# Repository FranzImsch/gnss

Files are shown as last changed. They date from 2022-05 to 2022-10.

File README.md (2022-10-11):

# [GNSS Rev. B](https://github.com/FranzImsch/gnss)

# Overview

[ZED-F9P](https://www.u-blox.com/sites/default/files/ZED-F9P-04B_DataSheet_UBX-21044850.pdf)\-based GNSS dev board with [ISM330DHCX](https://www.st.com/resource/en/datasheet/ism330dhcx.pdf) 6-DoF IMU, [BMM150](https://www.bosch-sensortec.com/media/boschsensortec/downloads/datasheets/bst-bmm150-ds001.pdf) Magnetometer and [DPS310](https://www.infineon.com/dgdl/Infineon-DPS310-DS-v01_00-EN.pdf?fileId=5546d462576f34750157750826c42242) pressure sensor.

As a basic UI, the OLED (1.5") can be used along with a navigation switch, more advanced usage requires a web interface. The device features a microSD card reader for data logging.

The ESP32 is used as the microcontroller because of its WiFi and Bluetooth capability that enables data to be streamed onto a device (phone, tablet, …) wirelessly.

The component selection is partly influenced by the semiconductor shortage. The software is yet to be worked on and also the documentation should receive some attention.

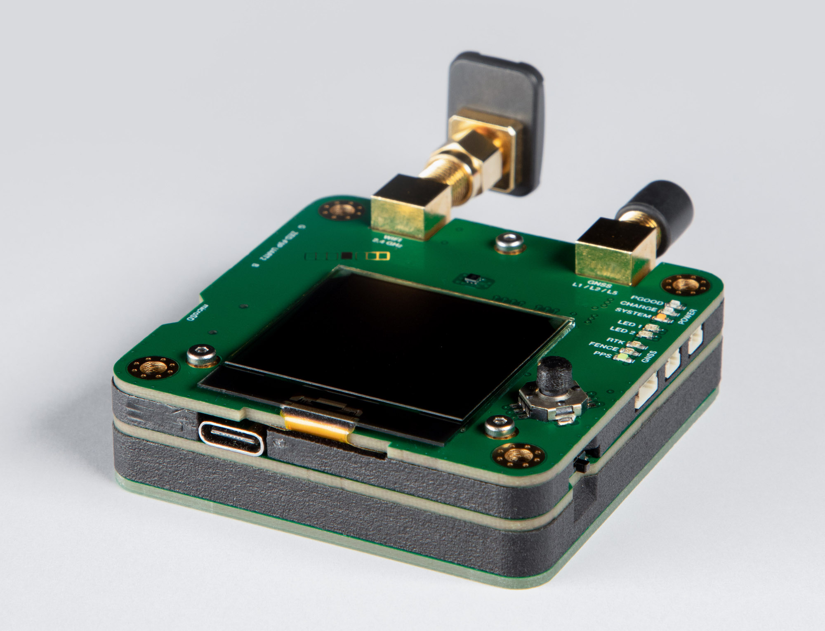
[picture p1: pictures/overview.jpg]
Overview (https://a360.co/38VXSXv)


# Hardware

The device consists of a stackup of three PCBs. A detailed view is provided by the [3D-model](https://a360.co/38VXSXv). The third PCB is not relevant for the function, as it only serves as a mounting piece for the battery.

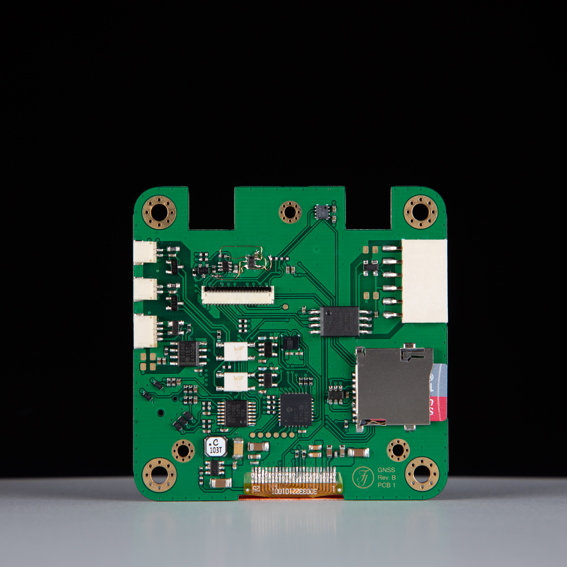
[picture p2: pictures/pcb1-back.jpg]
Photo of the backside of the PCB with the OLED
 The uppermost PCB of the stackup is where the OLED is mounted along with the navigation switch and some status LEDs. The photo shows the backside of this PCB with the IO ports and their isolation. Also found here is the barometric pressure sensor (top), a port expander and the 12V step-up converter for the OLED. One may ignore the little bodge at the top. :)

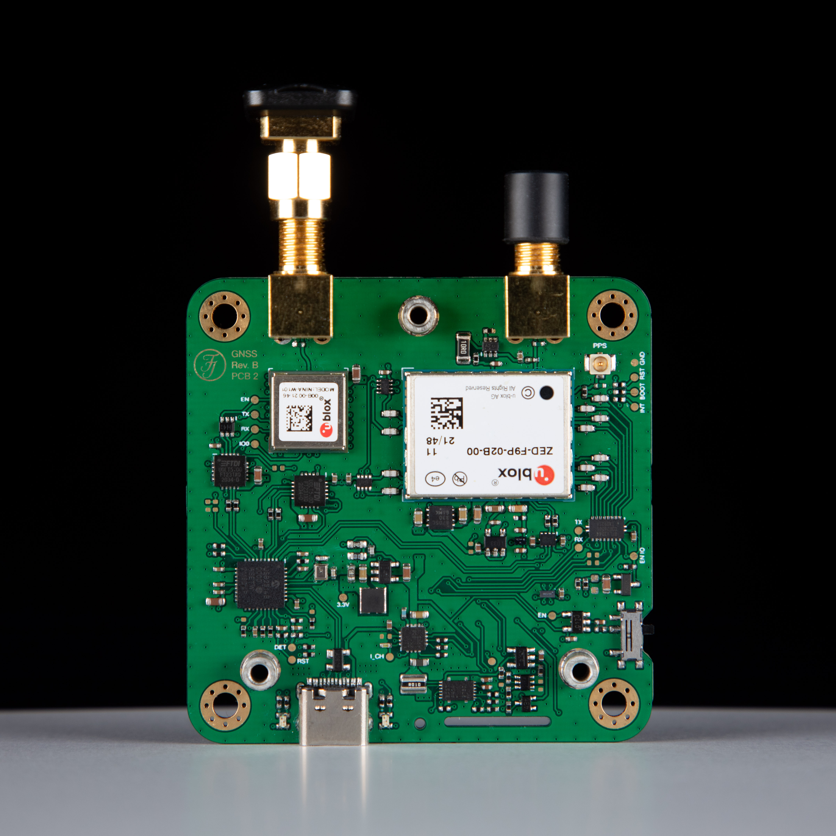
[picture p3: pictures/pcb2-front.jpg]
Photo of PCB with ZED module
 The picture shows the main PCB where the ZED module is located (right-hand side). On the left the ESP32 module can be found along with the FTDI chips for both the ESP and the UART1 port of the ZED-F9P. The bottom left is where the USB hub chip is placed. On the bottom-right there is the power section, consisting of a step-down converter, a power path manager, a fuel gauge for the battery and some super low-noise LDOs for the ZED-F9P.

## Battery

The function of the battery circuitry was tested extensively and no issues were found. The device correctly stops power when the cutoff voltage is reaced (3.2 V, depends on the voltage supervisor). During charging, the unit does not exceed ca. 60°C at the hottest point (which is the power path IC).

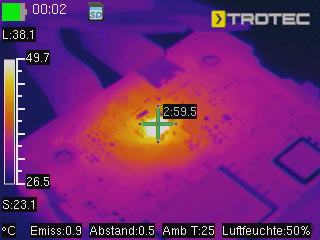
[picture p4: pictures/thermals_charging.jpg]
Thermal image of power path IC


## Documentation and Resources

[Schematic](https://franz.science/gnss/Schematic.pdf)  
[iBom PCB #1](https://franz.science/gnss/PCB-1/bom/index.html)  
[iBom PCB #2](https://franz.science/gnss/PCB-2/bom/index.html)

[3D model](https://a360.co/38VXSXv)

## Changelog (Rev A to B)

* Added LiPo battery to enable standalone operation
* Replaced BNO055 with ISM330DHCX and BMM150 due to their superior performance
* Removed SHT40 as the first revision revealed that the board heats up too much for temperature or humidity measurement (Can be added via exposed i2c connector)
* Added USB hub to board
* Protected ZED a bit more against electrical damage (isolating and filtering IO, LDO as power supply)
* many minor improvements

# GNSS in General

Useful literature:

* https://doi.org/10.1007/978-3-211-73017-1
* https://content.u-blox.com/sites/default/files/products/documents/GPS-Compendium_Book\_(GPS-X-02007).pdf?hash=undefined

---

# Licence

Copyright Franz Imschweiler 2022.

This source describes Open Hardware and is licensed under the CERN-OHL-S v2 or any later version. You may redistribute and modify this source and make products using it under the terms of the CERN-OHL-S v2 or any later version (https://ohwr.org/cern_ohl_s_v2.txt).

This source is distributed WITHOUT ANY EXPRESS OR IMPLIED WARRANTY, INCLUDING OF MERCHANTABILITY, SATISFACTORY QUALITY AND FITNESS FOR A PARTICULAR PURPOSE. Please see the CERN-OHL-S v2 for applicable conditions.

Source location: https://github.com/FranzImsch/gnss

As per CERN-OHL-S v2 section 4, should You produce hardware based on this source, You must where practicable maintain the Source Location visible on the external case of the GNSS Receiver or other products you make using this source.

---

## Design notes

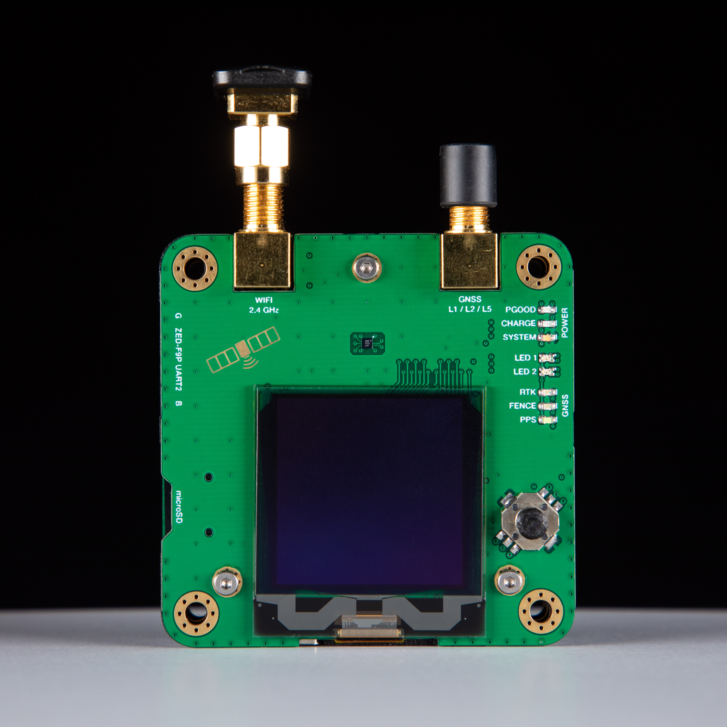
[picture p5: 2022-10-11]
pictures/pcb1-front.jpg

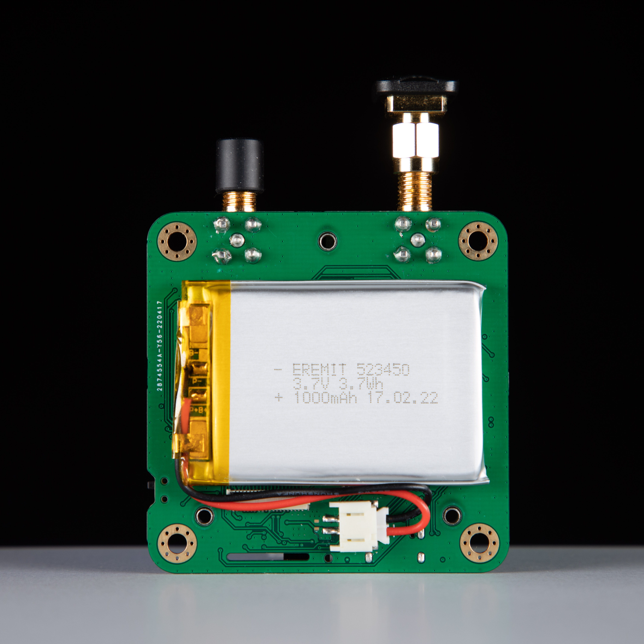
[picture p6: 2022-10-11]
pictures/pcb2-back.jpg

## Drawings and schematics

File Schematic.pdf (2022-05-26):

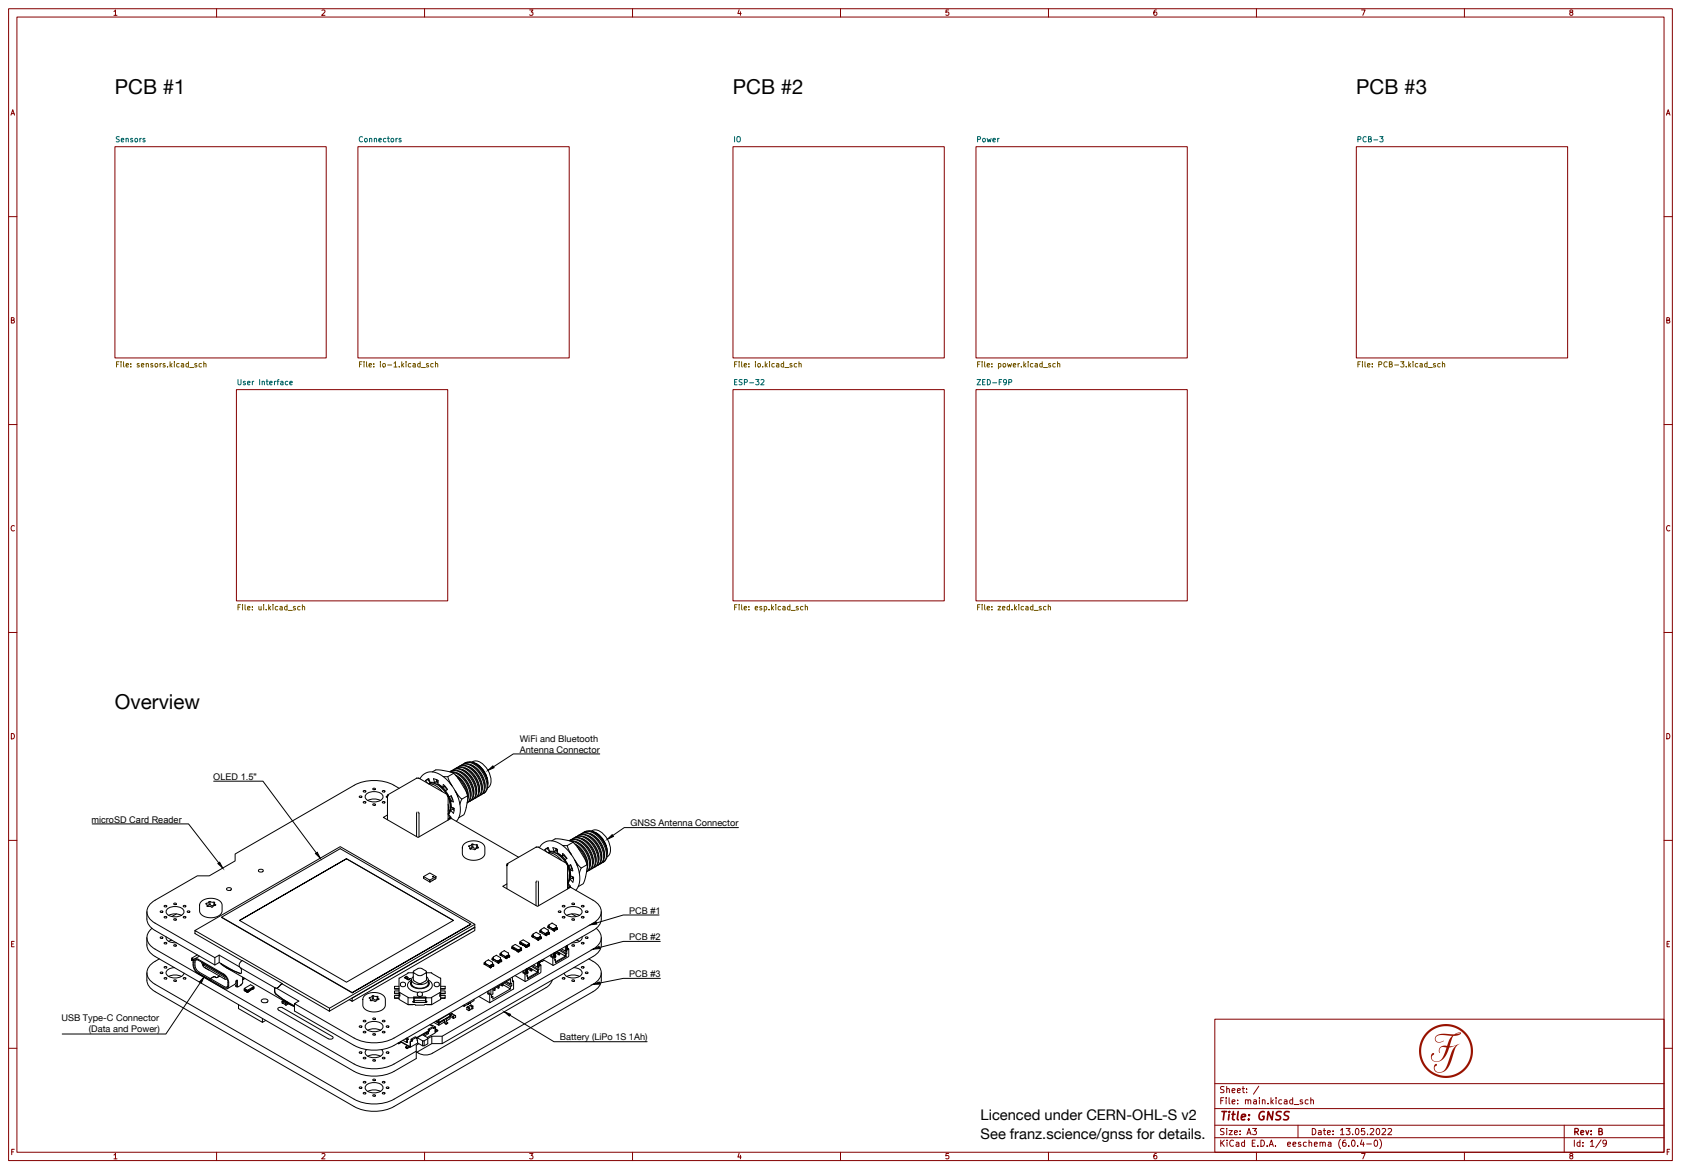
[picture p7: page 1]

Licenced under CERN-OHL-S v2
See franz.science/gnss for details.

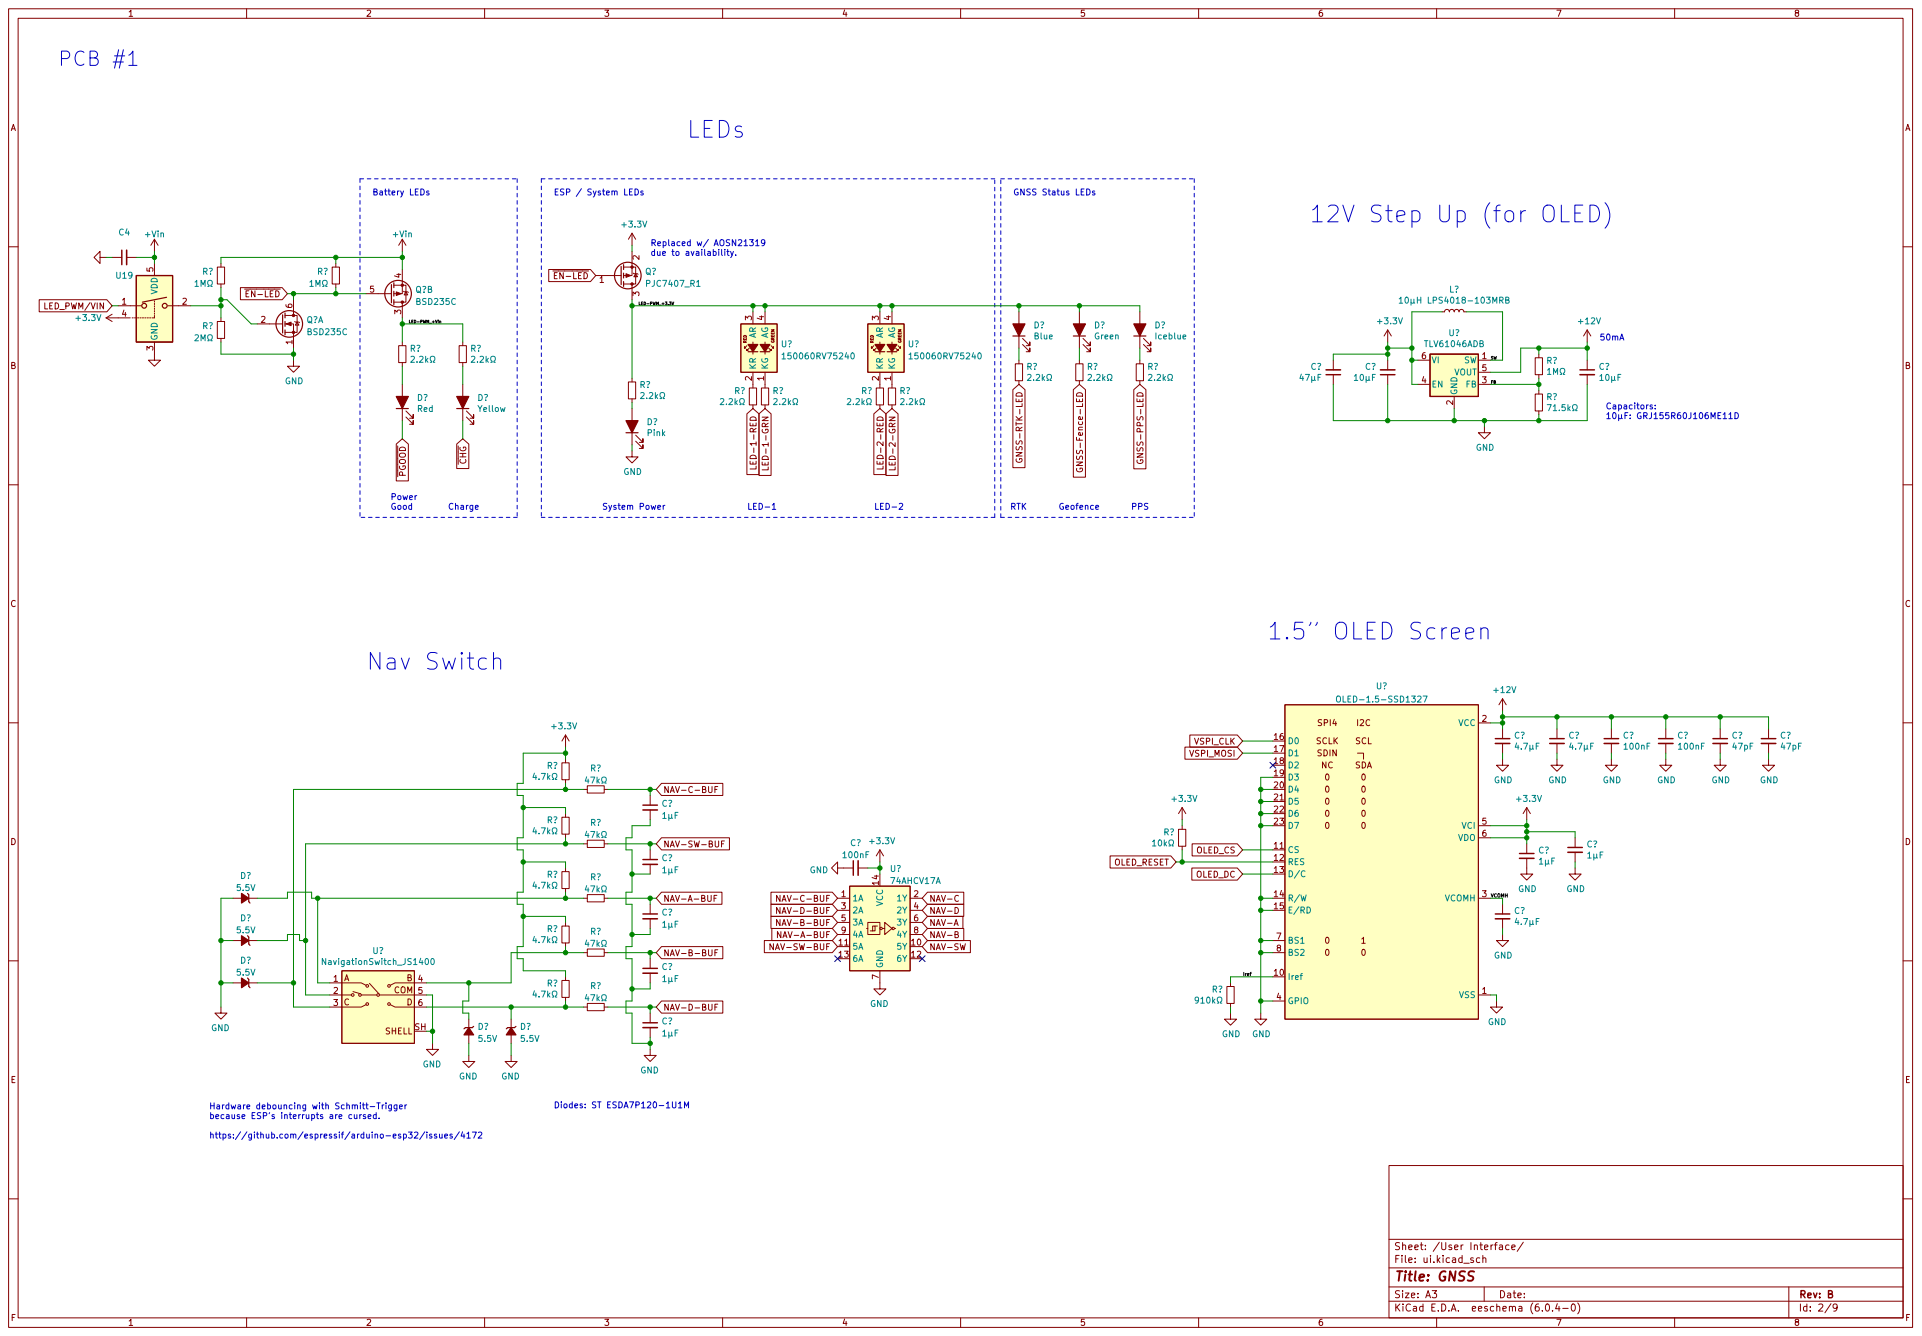
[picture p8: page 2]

12V Step Up (for OLED)

Hardware debouncing with Schmitt-Trigger
because ESP's interrupts are cursed.

https://github.com/espressif/arduino-esp32/issues/4172

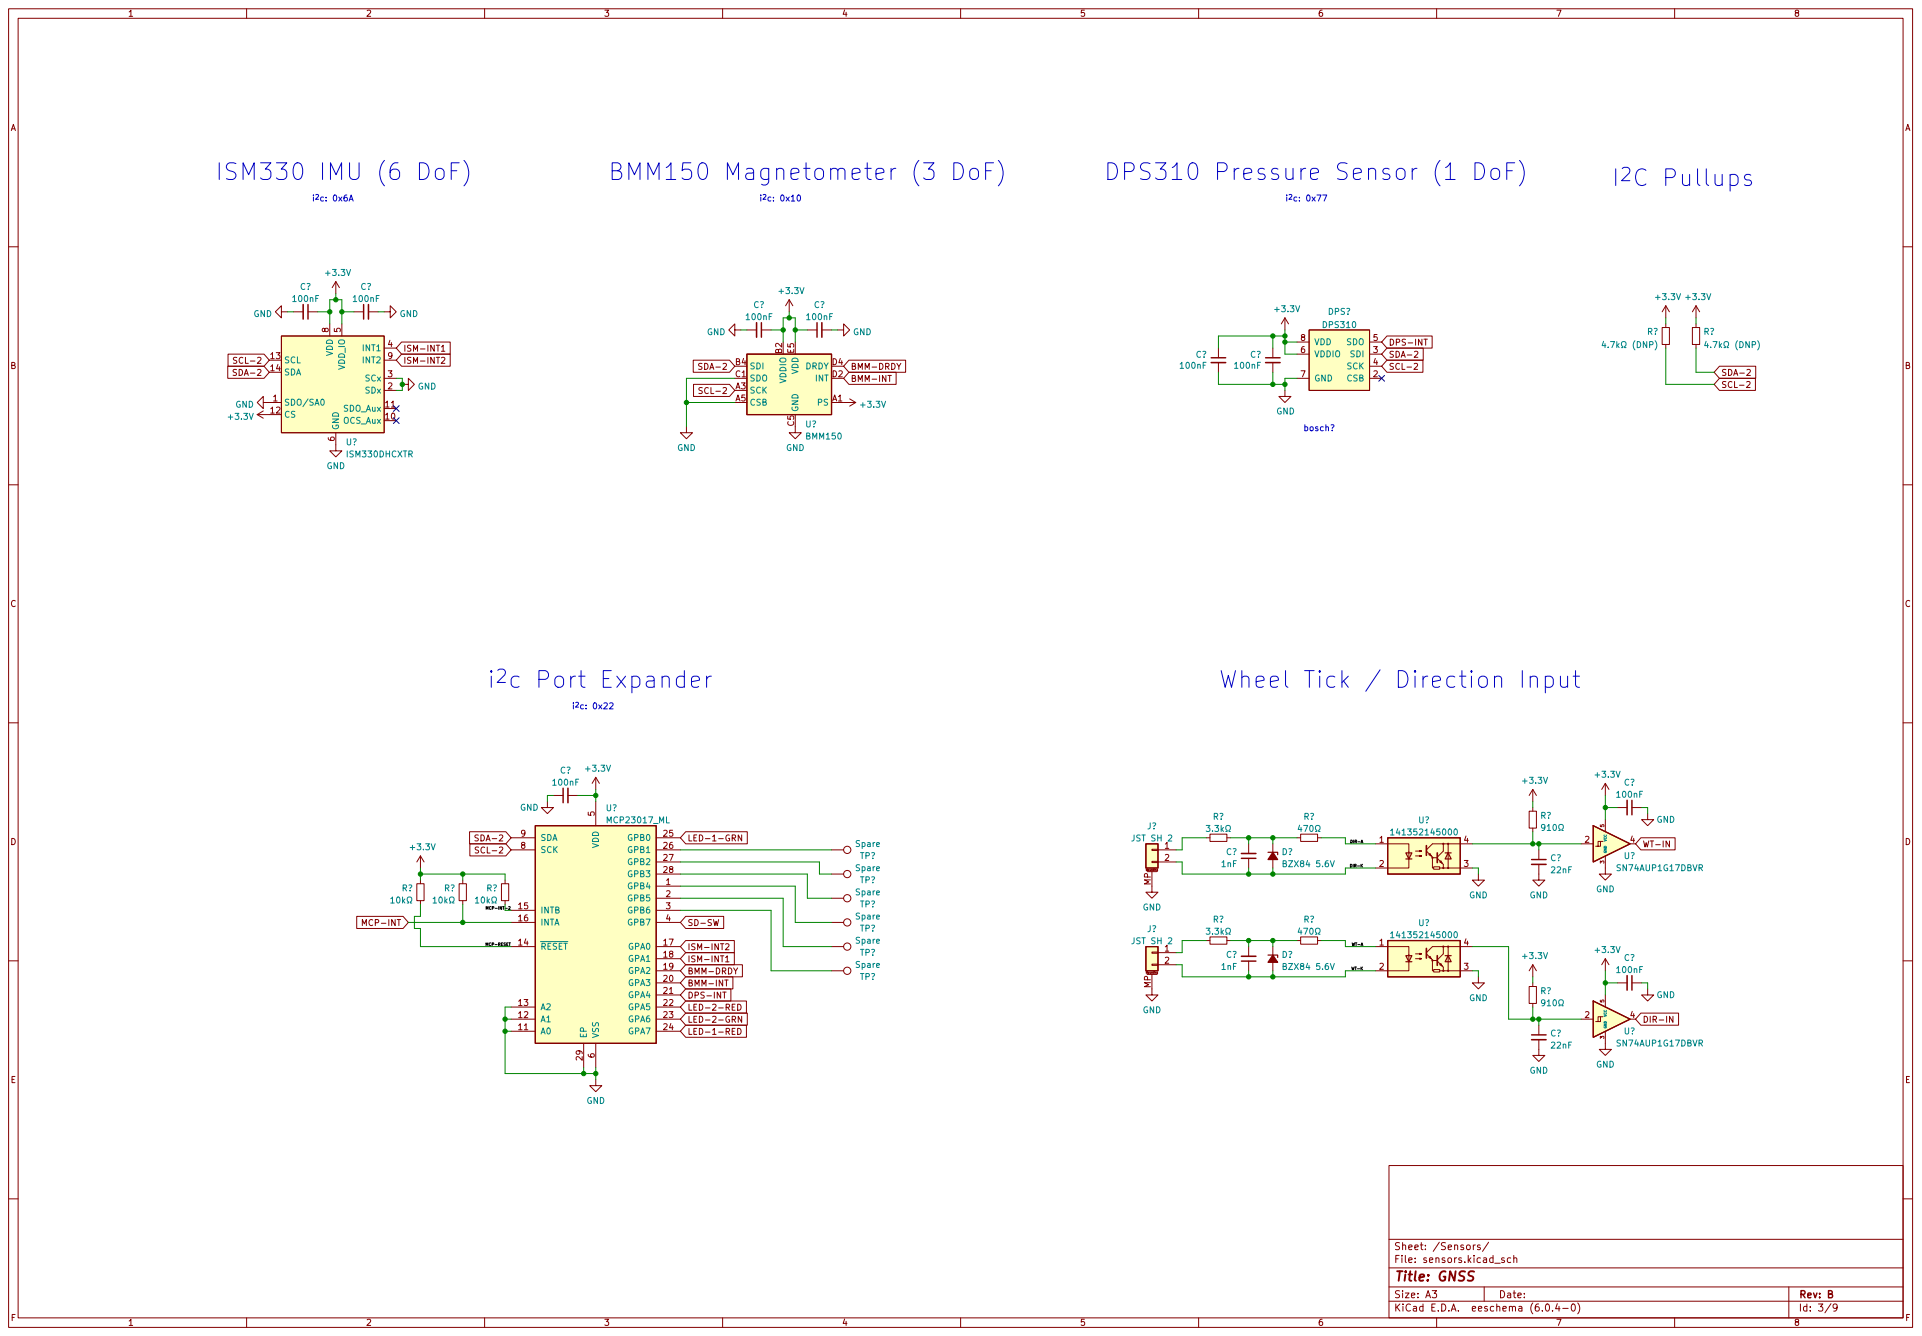
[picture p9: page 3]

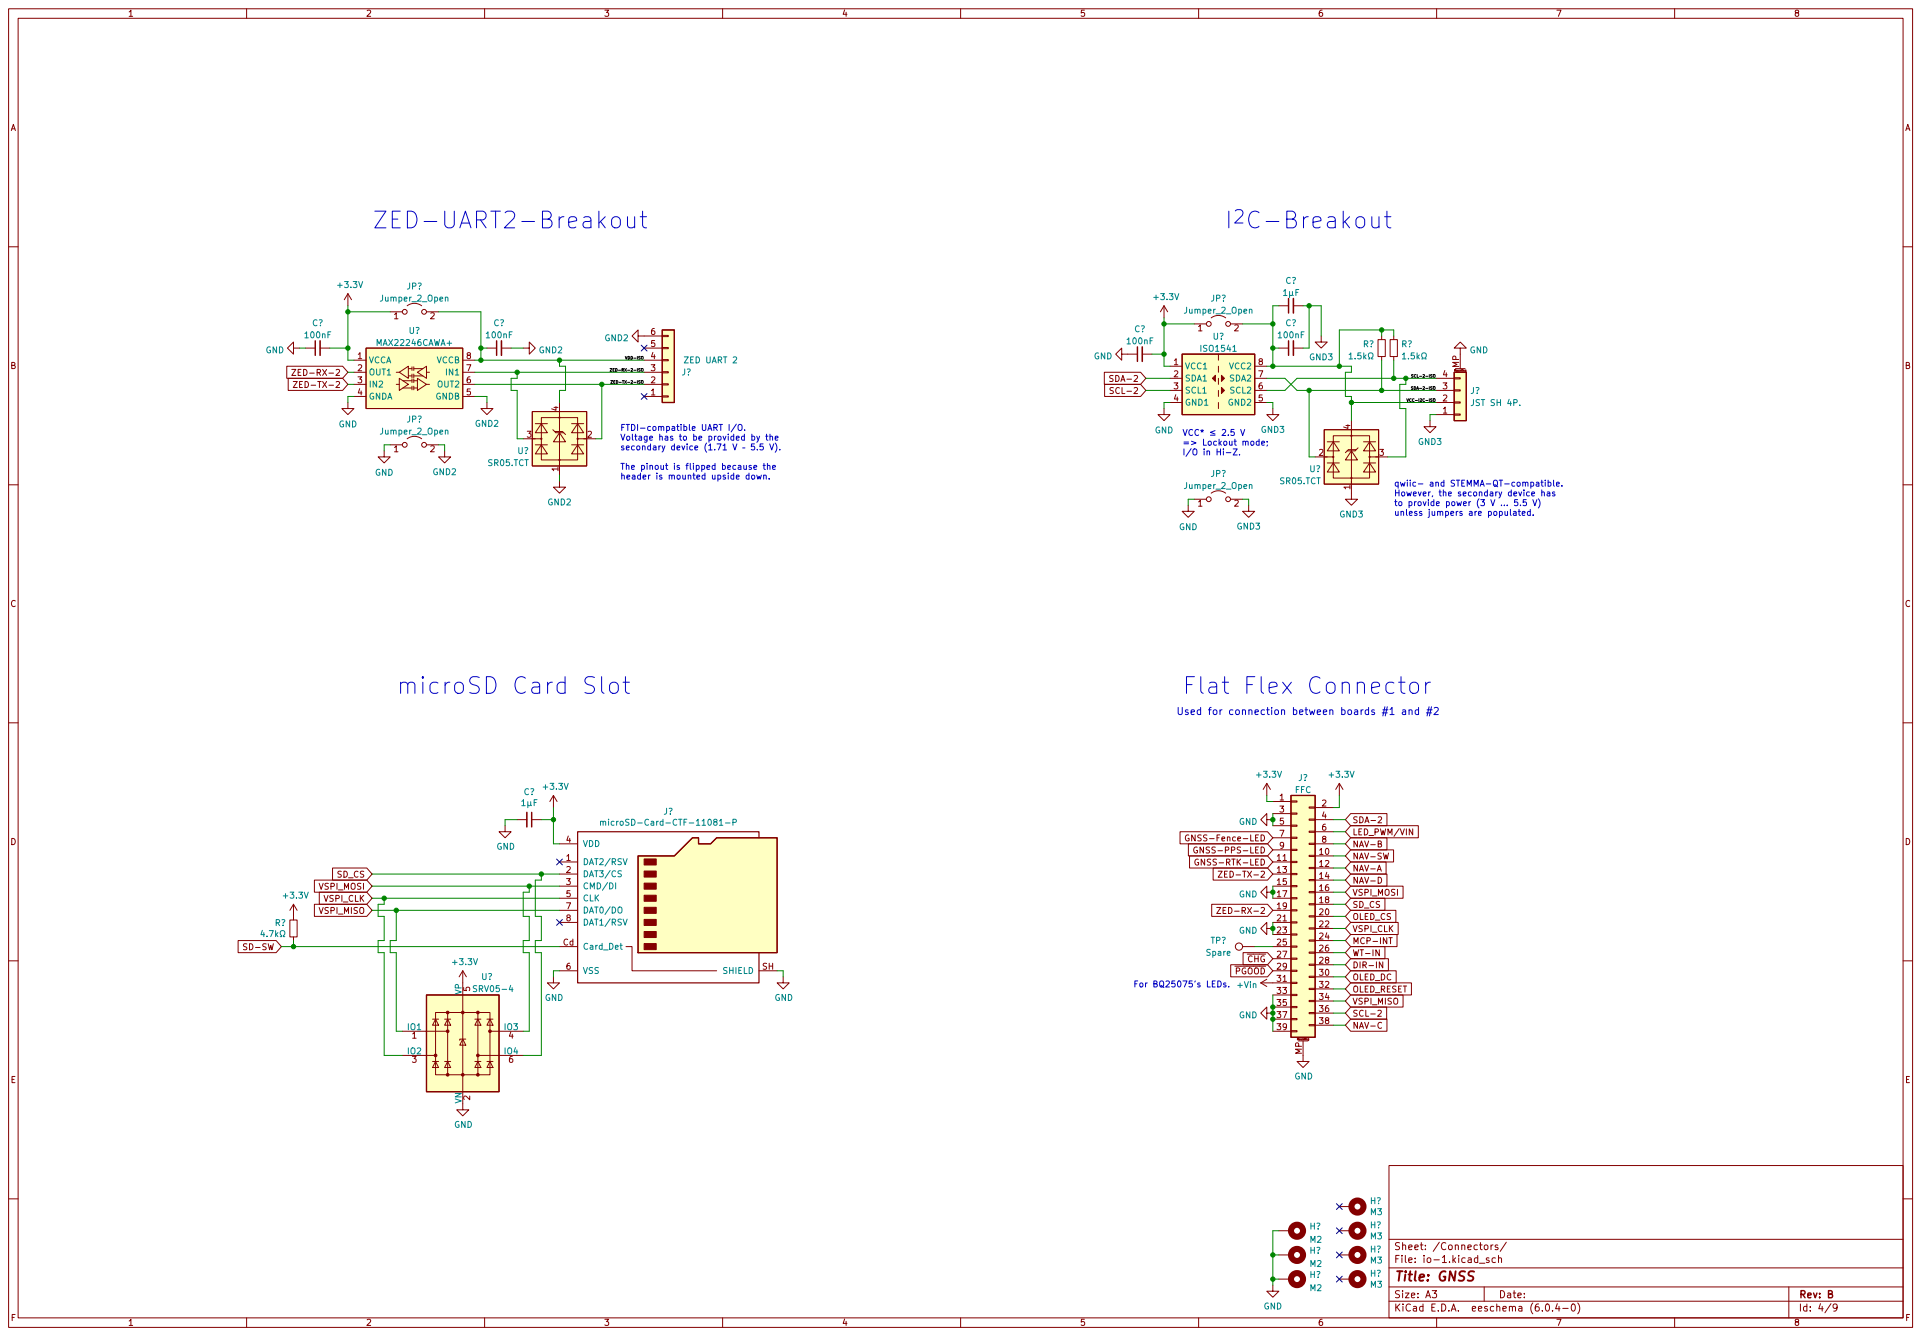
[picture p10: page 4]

FTDI-compatible UART I/O.
Voltage has to be provided by the

The pinout is flipped because the
header is mounted upside down.

qwiic- and STEMMA-QT-compatible.
However, the secondary device has
unless jumpers are populated.

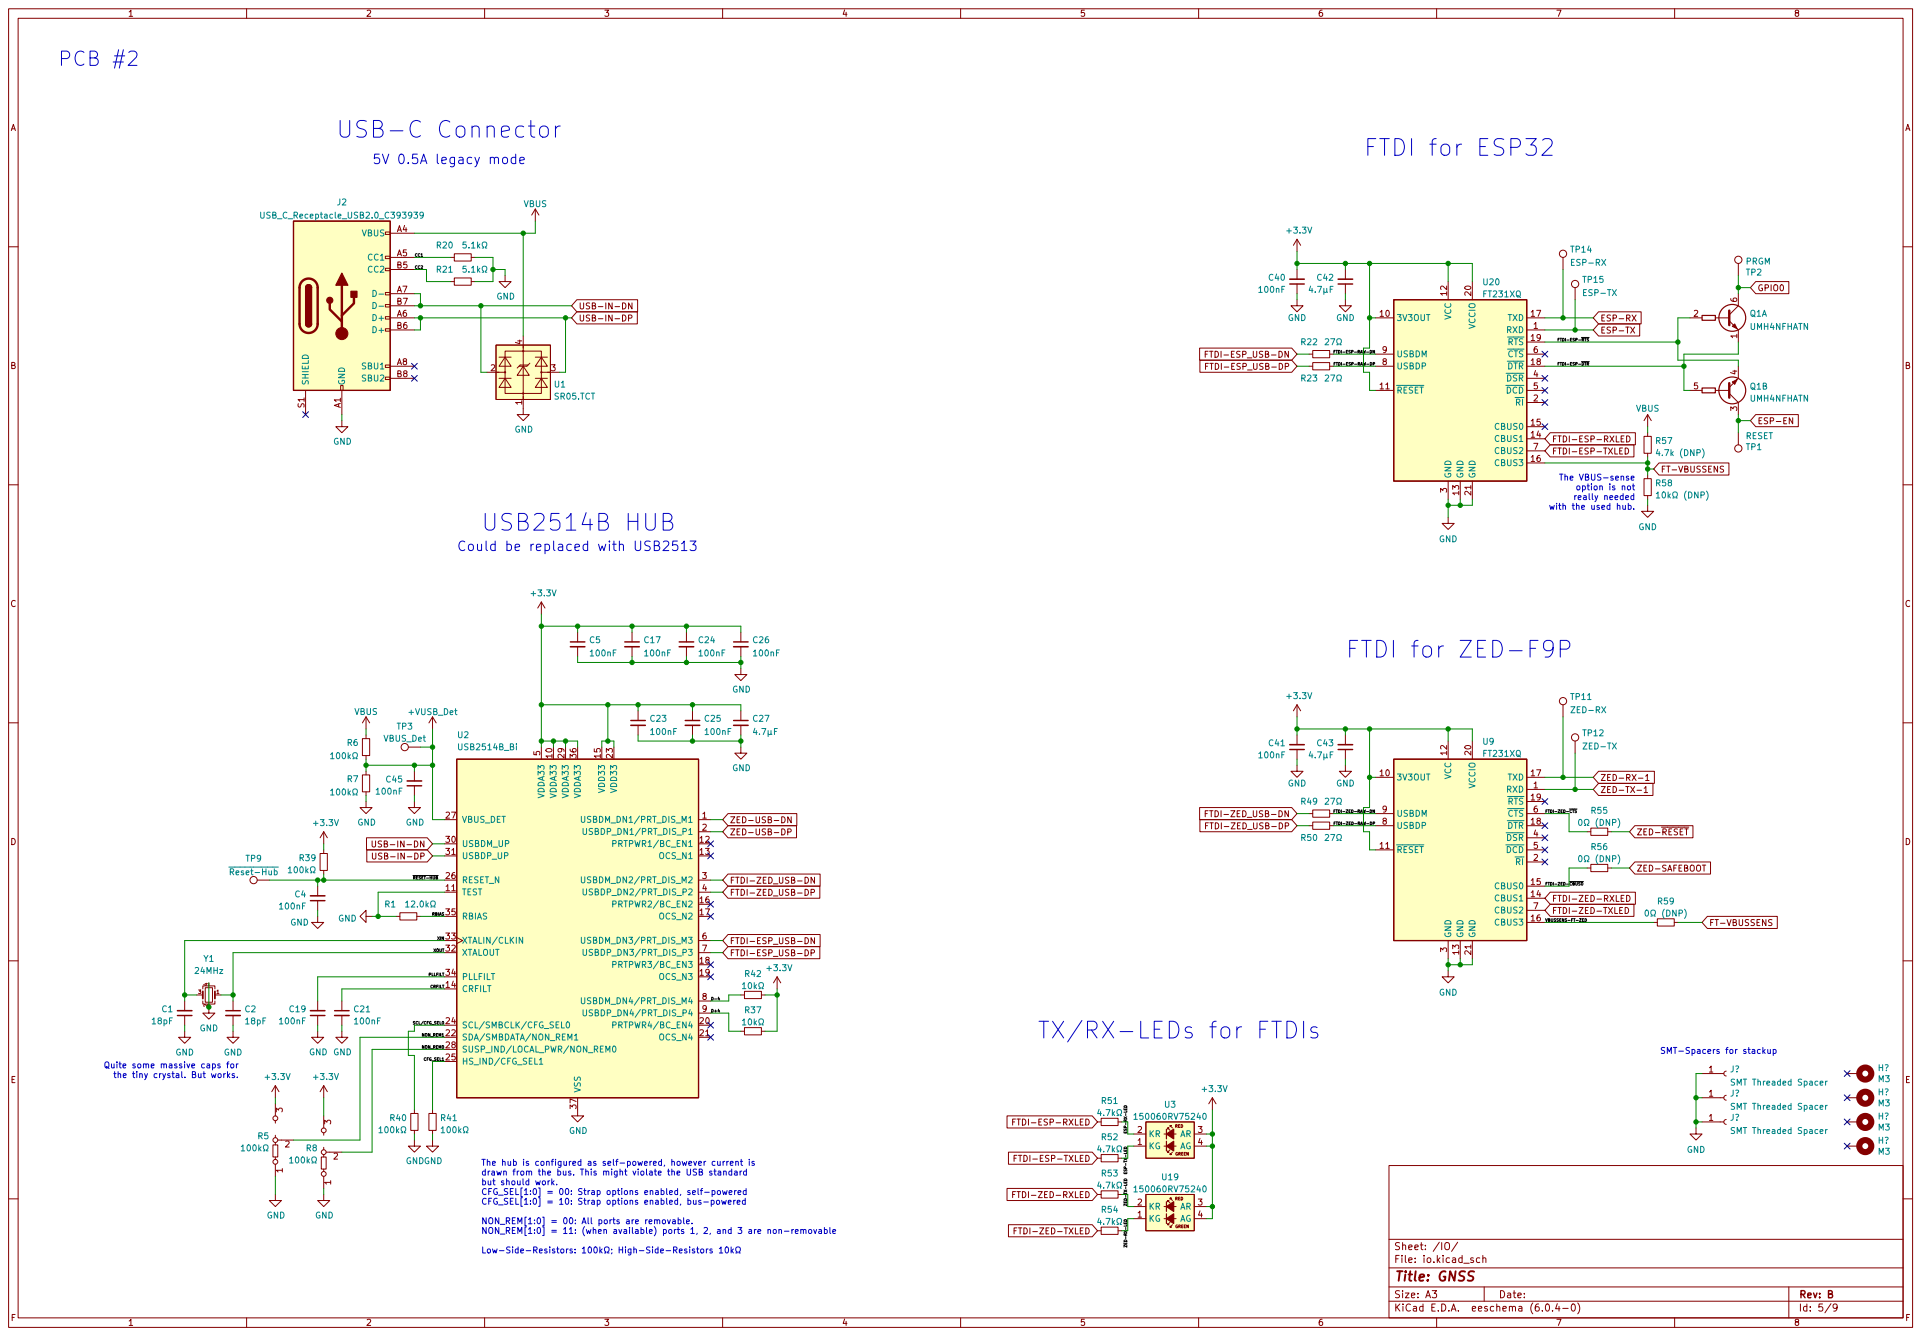
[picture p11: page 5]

FTDI-ESP-RAW-DN

FTDI-ESP-RAW-DP

The VBUS-sense
option is not
really needed
with the used hub.

Could be replaced with USB2513

FTDI-ZED_USB-DN ZED-USB-DN

FTDI-ZED-RAW-DN

FTDI-ZED-RAW-DP

TX/RX-LEDs for FTDIs

SMT-Spacers for stackup

Quite some massive caps for
the tiny crystal. But works.

The hub is configured as self-powered, however current is
drawn from the bus. This might violate the USB standard
but should work.
CFG_SEL[1:0] = 00: Strap options enabled, self-powered
CFG_SEL[1:0] = 10: Strap options enabled, bus-powered

NON_REM[1:0] = 00: All ports are removable.
NON_REM[1:0] = 11: (when available) ports 1, 2, and 3 are non-removable

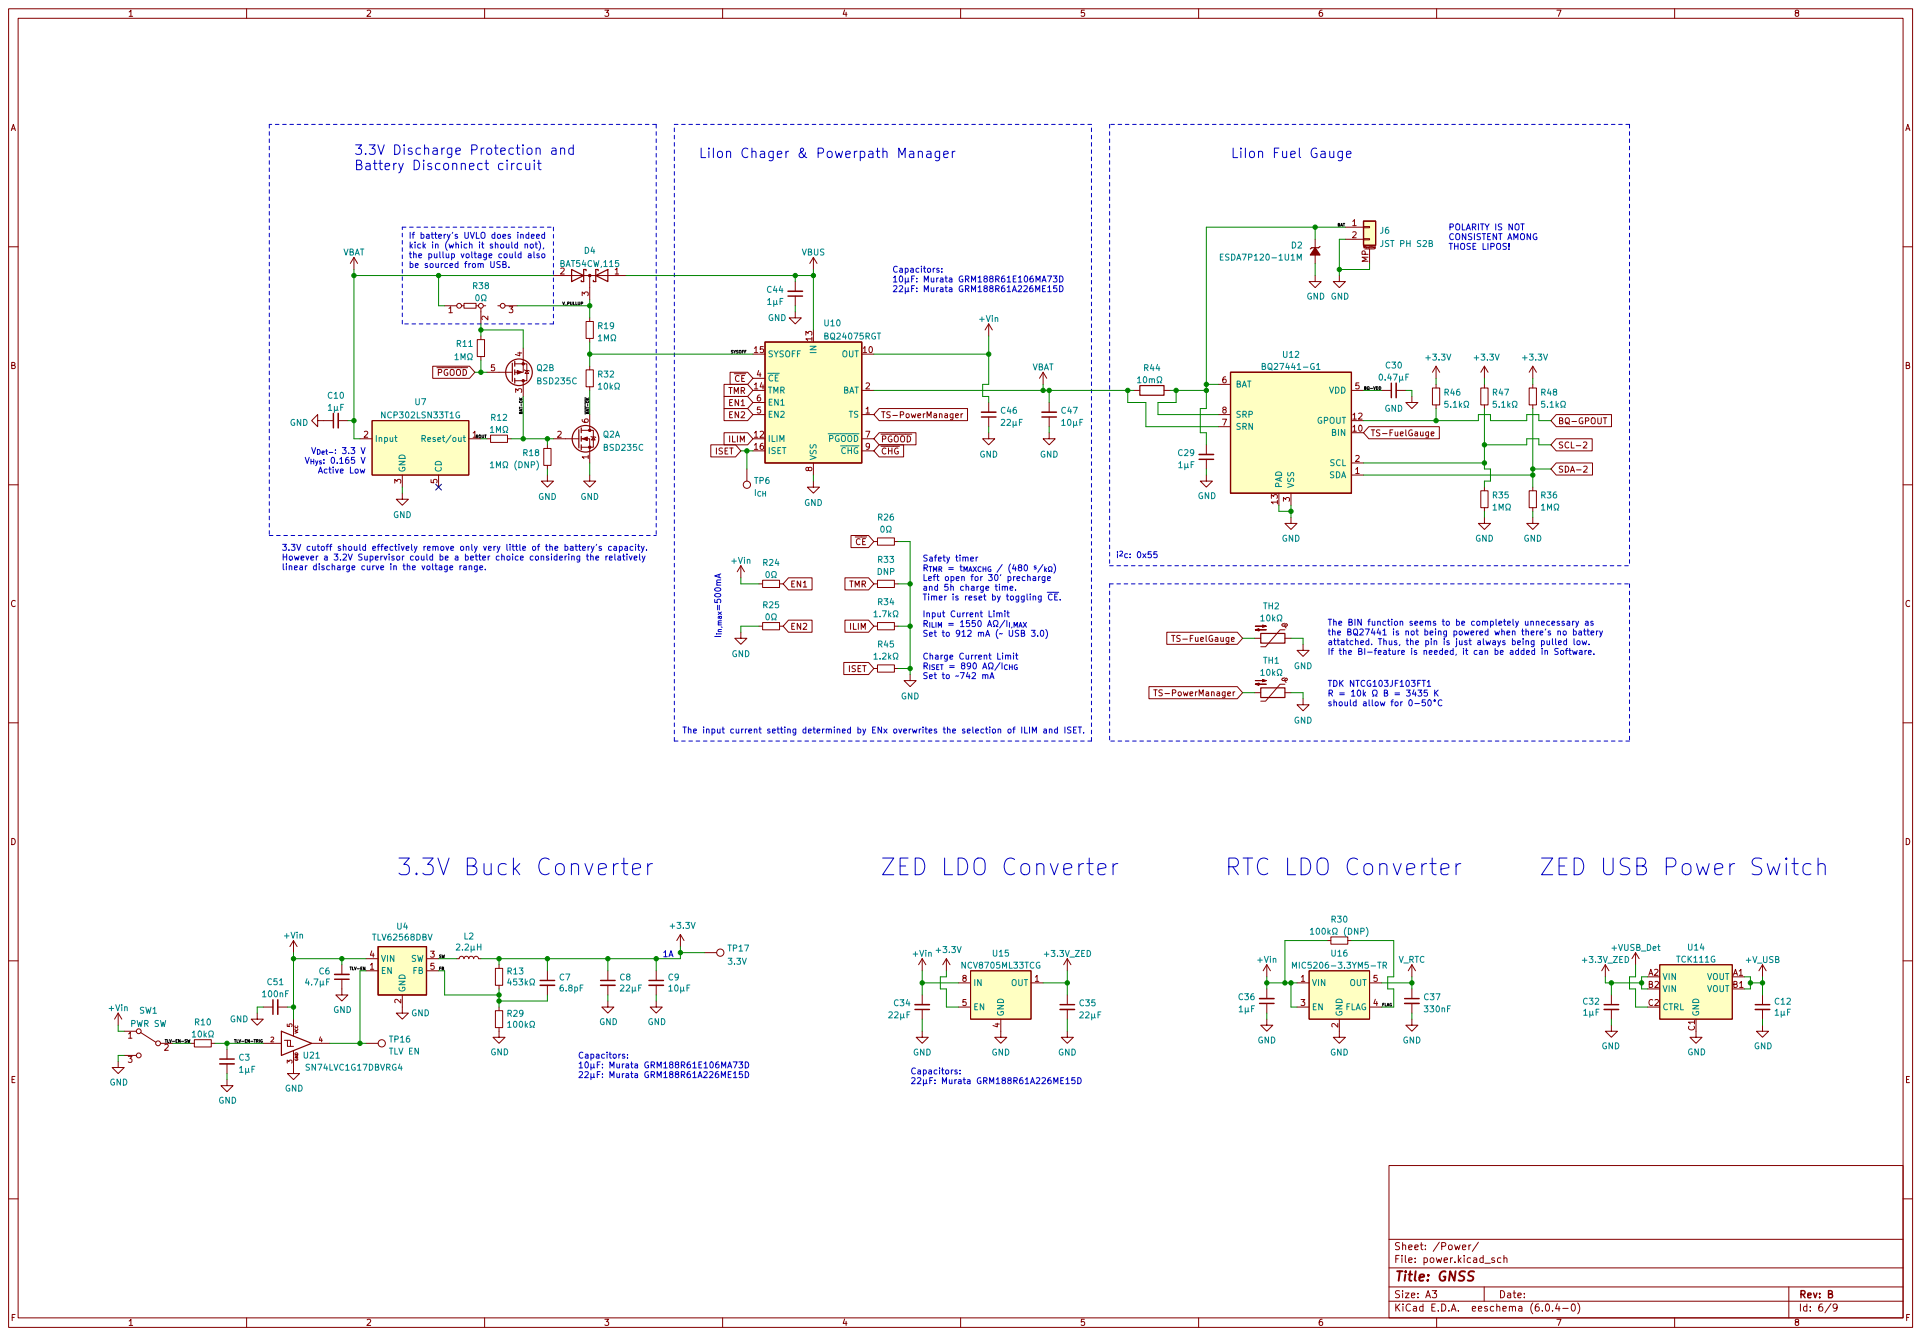
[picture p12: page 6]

If battery's UVLO does indeed
kick in (which it should not),
the pullup voltage could also
be sourced from USB.

3.3V cutoff should effectively remove only very little of the battery's capacity.
However a 3.2V Supervisor could be a better choice considering the relatively
linear discharge curve in the voltage range.

Safety timer
Left open for 30' precharge
and 5h charge time.
Timer is reset by toggling ~{CE}.

Input Current Limit
Set to 912 mA (~ USB 3.0)

The BIN function seems to be completely unnecessary as
the BQ27441 is not being powered when there's no battery
attatched. Thus, the pin is just always being pulled low.
If the BI-feature is needed, it can be added in Software.

The input current setting determined by ENx overwrites the selection of ILIM and ISET.

ZED USB Power Switch

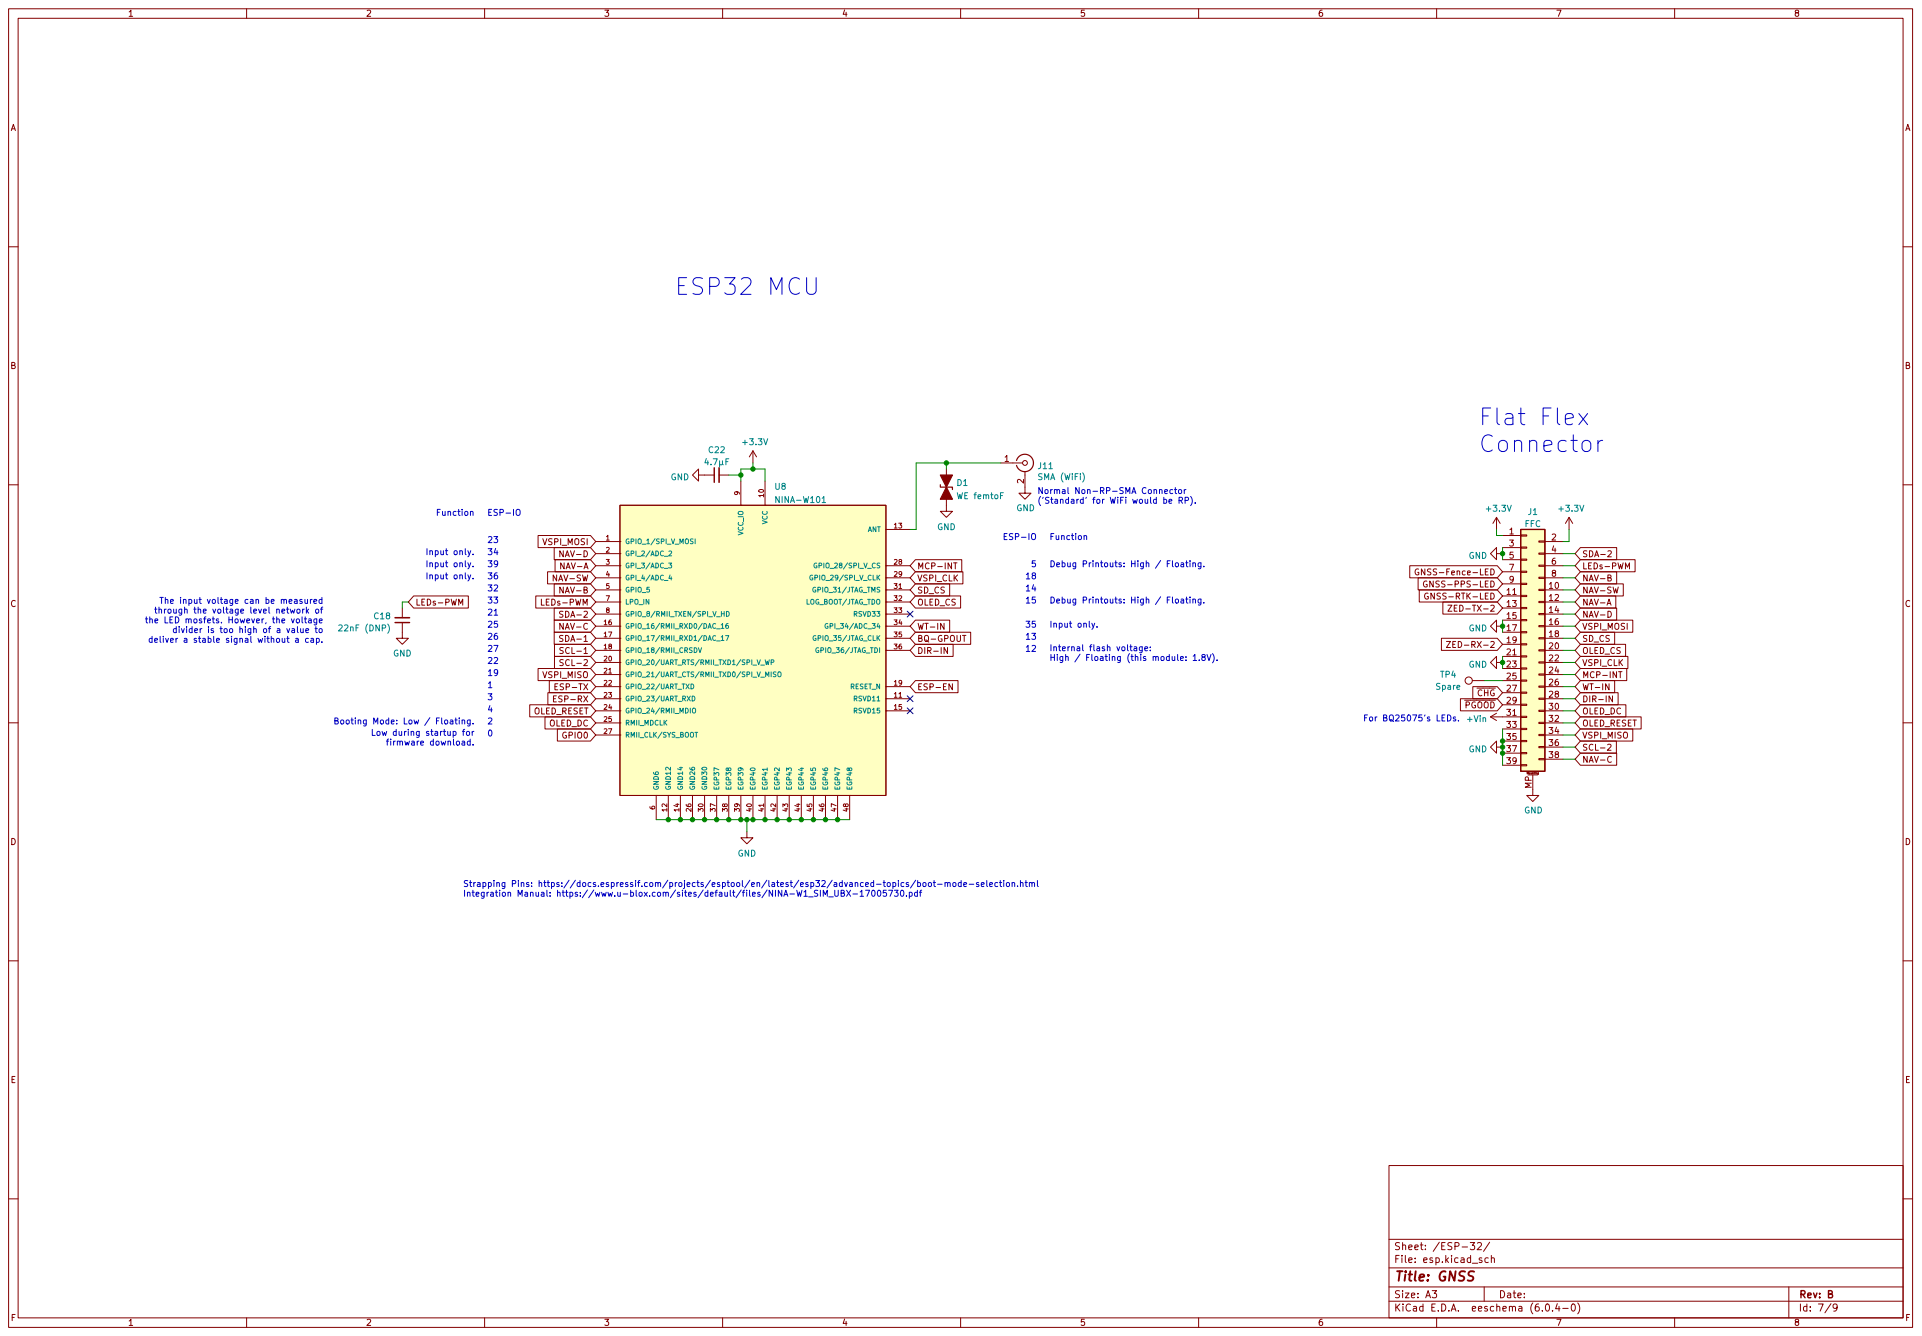
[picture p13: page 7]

SMA (WiFi)
Normal Non-RP-SMA Connector
('Standard' for WiFi would be RP).
GND

Debug Printouts: High / Floating.

The input voltage can be measured
through the voltage level network of
the LED mosfets. However, the voltage

divider is too high of a value to

Internal flash voltage:
High / Floating (this module: 1.8V).

Booting Mode: Low / Floating.

Low during startup for
firmware download.

Strapping Pins: https://docs.espressif.com/projects/esptool/en/latest/esp32/advanced-topics/boot-mode-selection.html
Integration Manual: https://www.u-blox.com/sites/default/files/NINA-W1_SIM_UBX-17005730.pdf

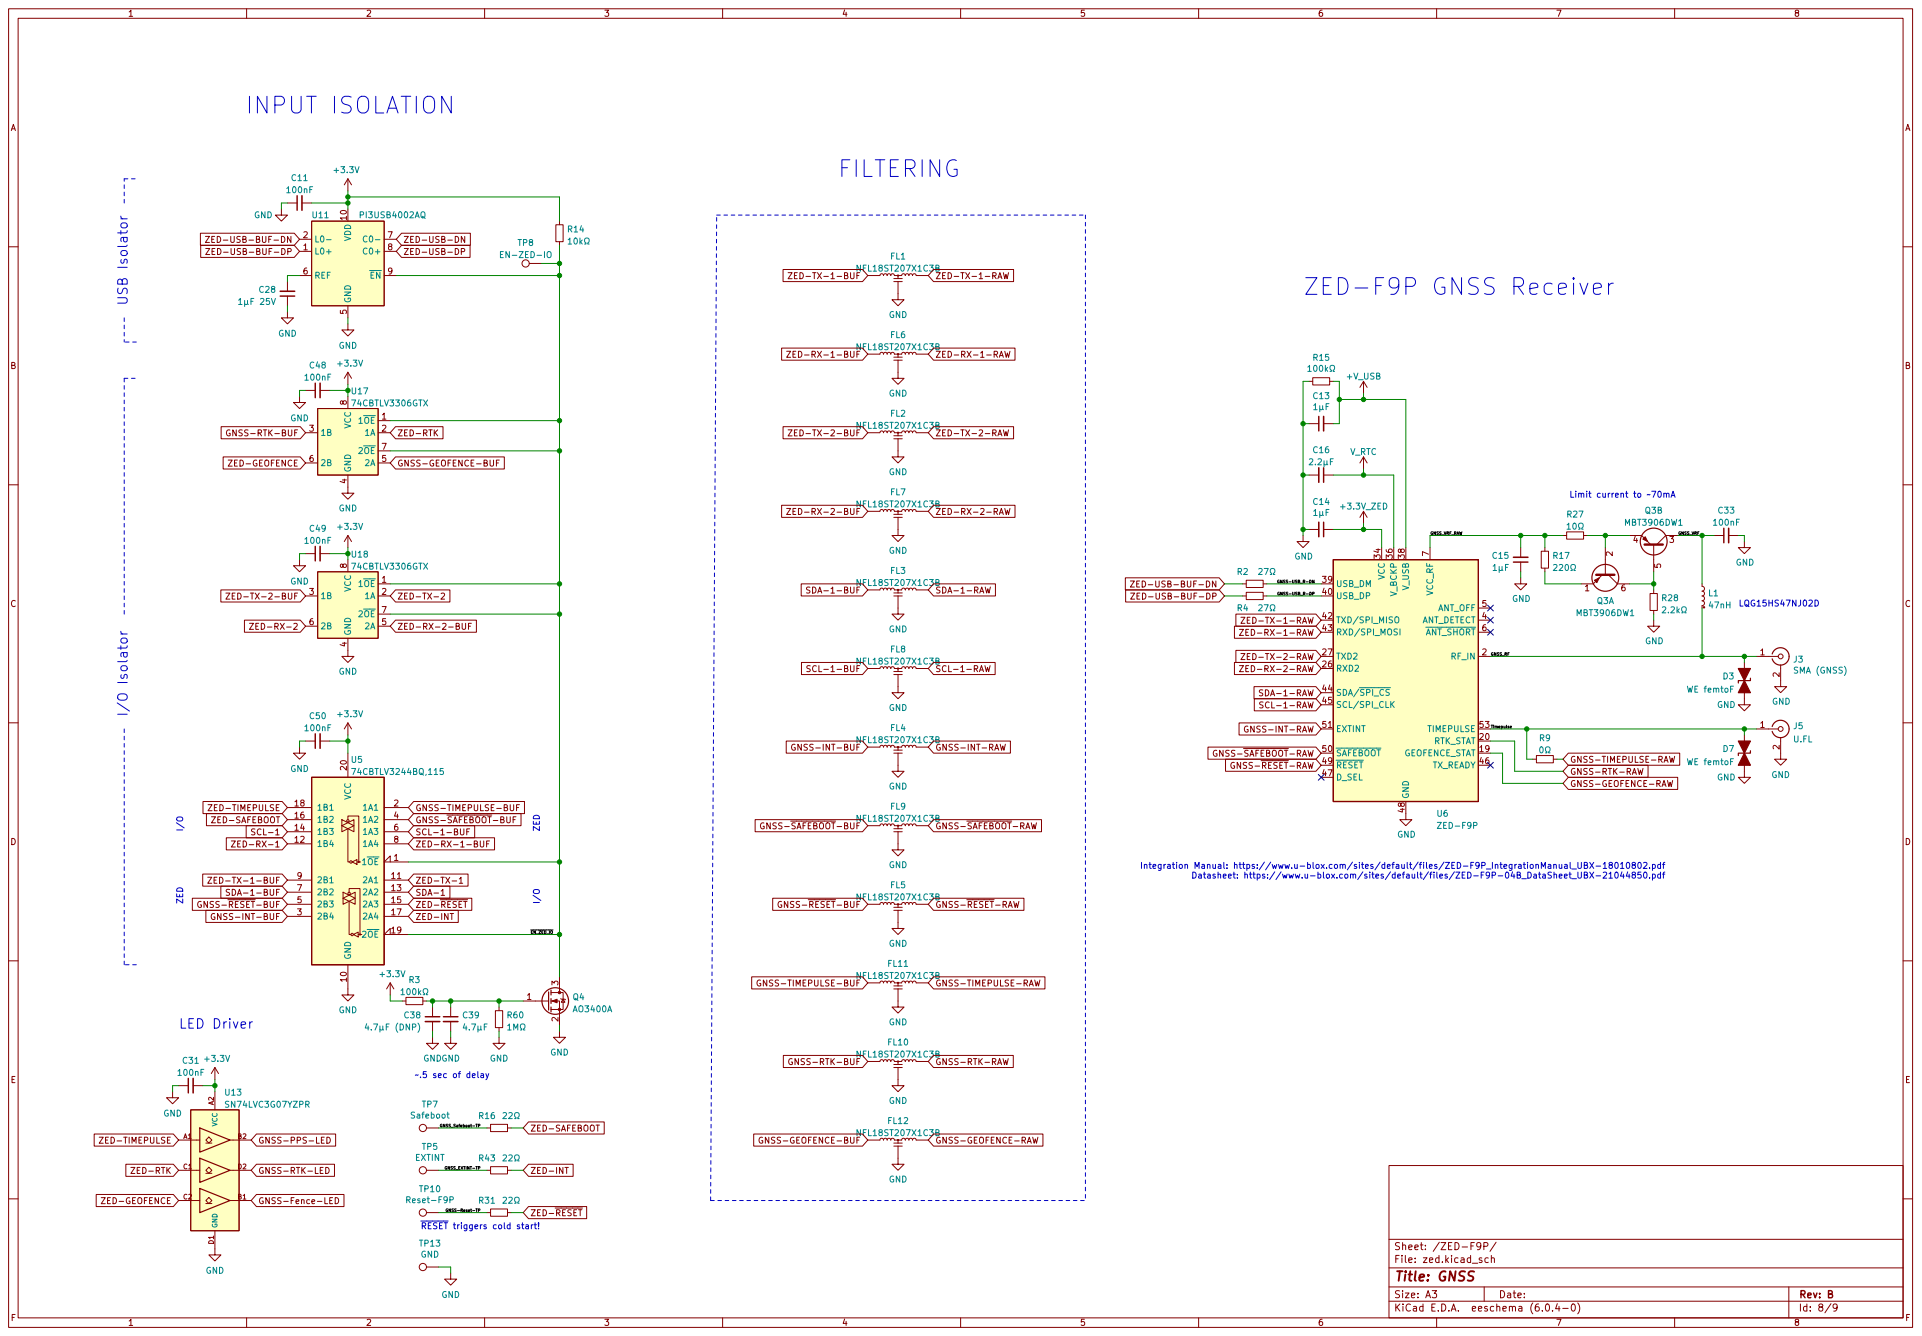
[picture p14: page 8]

ZED-USB-BUF-DN
ZED-USB-BUF-DP

GNSS-TIMEPULSE-RAW GNSS-~{SAFEBOOT}-RAW
GNSS-RTK-RAW GNSS-~{RESET}-RAW

Integration Manual: https://www.u-blox.com/sites/default/files/ZED-F9P_IntegrationManual_UBX-18010802.pdf

Datasheet: https://www.u-blox.com/sites/default/files/ZED-F9P-04B_DataSheet_UBX-21044850.pdf

~{RESET} triggers cold start!

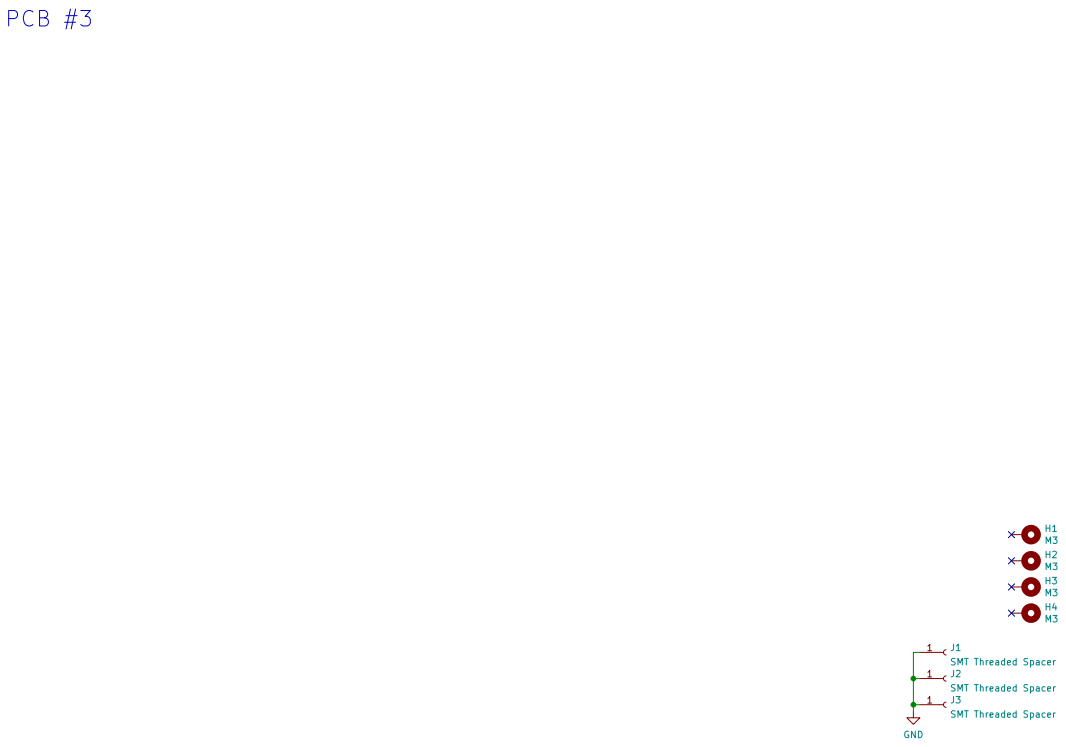
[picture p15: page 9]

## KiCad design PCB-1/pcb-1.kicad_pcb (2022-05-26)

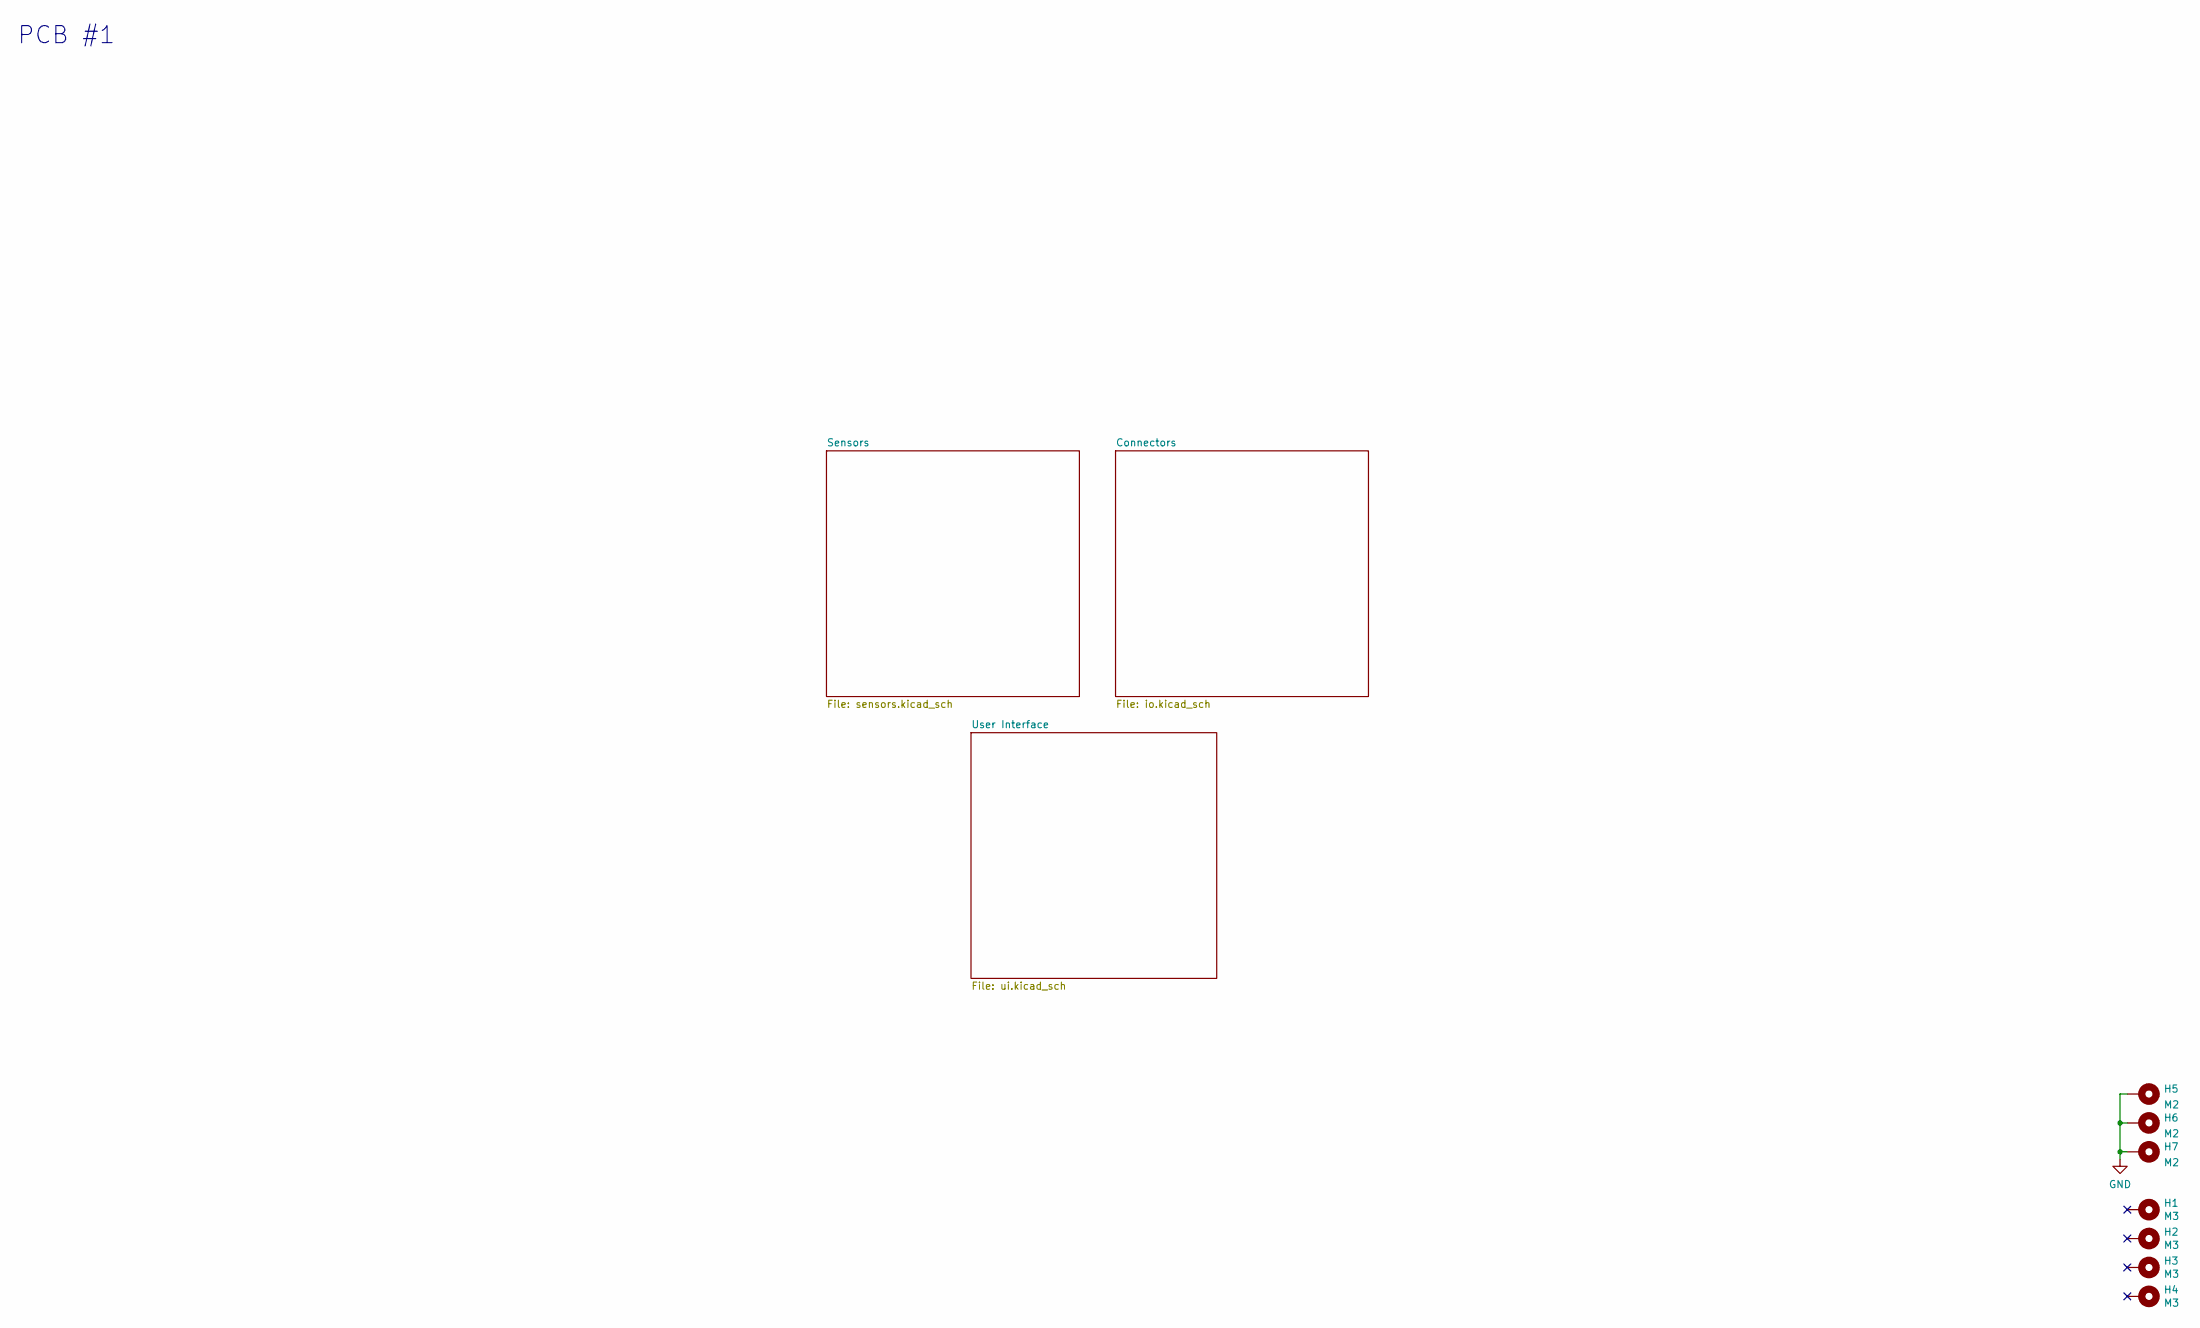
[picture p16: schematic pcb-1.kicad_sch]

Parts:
H1, H2, H3, H4: M3; MountingHole_3.2mm_M3_Pad_Via_NoSilk
H5, H6, H7: M2; MountingHole_2.2mm_M2_Pad_Via_NoSilk

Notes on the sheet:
PCB #1

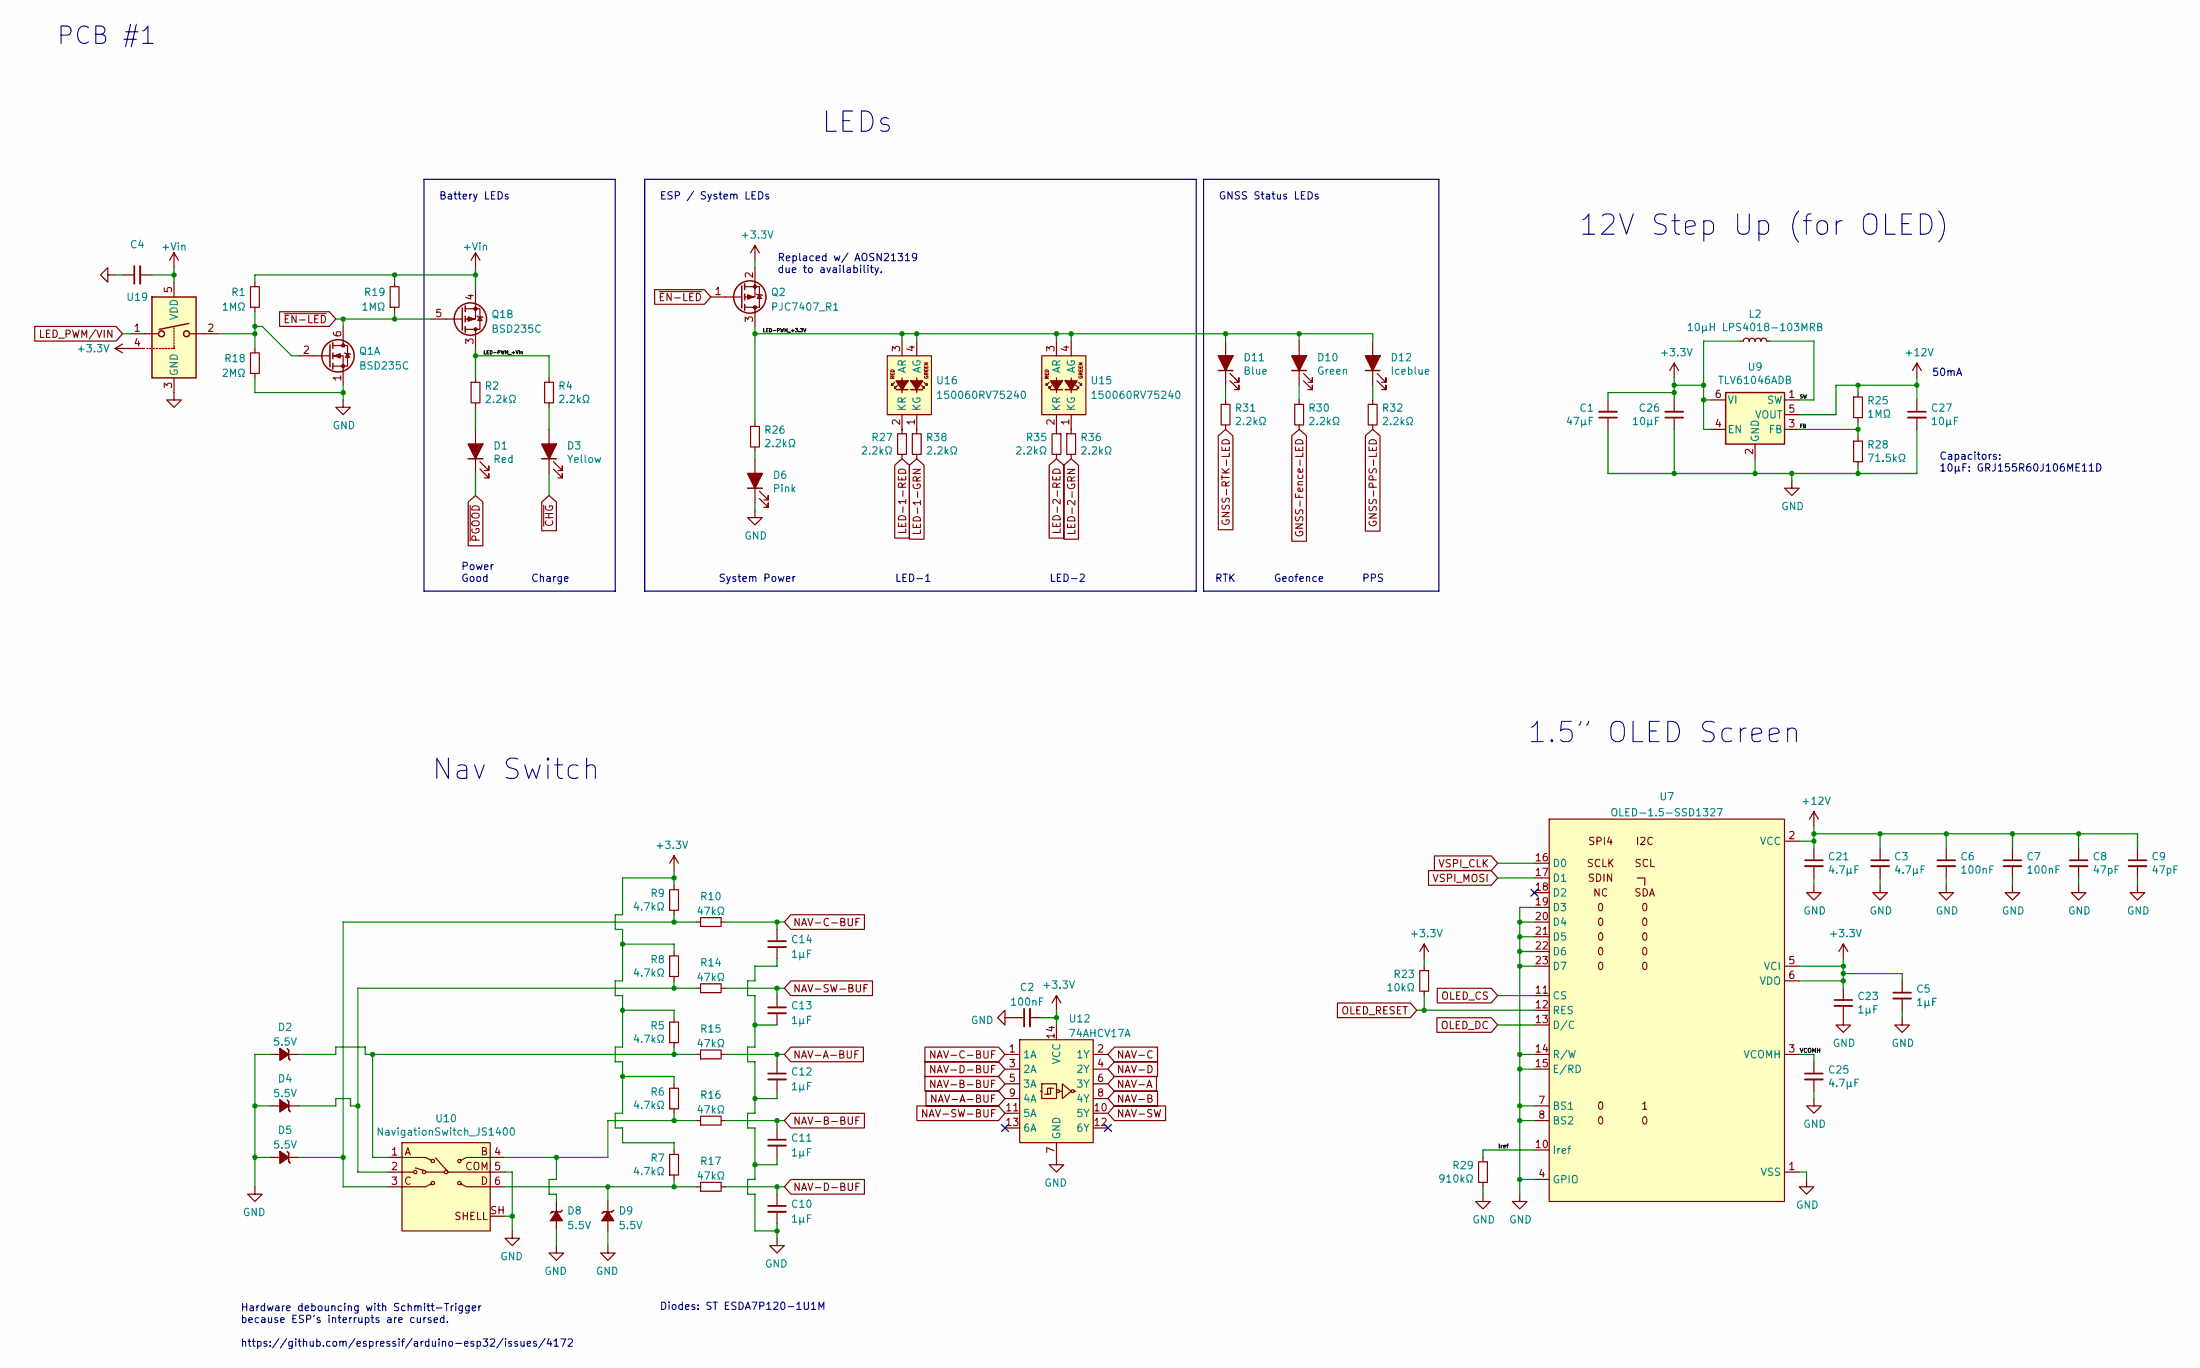
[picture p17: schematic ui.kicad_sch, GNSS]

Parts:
C1: 47µF; C_1206_3216Metric_NoSilk
C2: 100nF; C_0402_1005Metric_NoSilk
C3, C21: 4.7µF; C_1206_3216Metric_NoSilk
C4: (no value)
C5, C23: 1µF; C_0603_1608Metric_NoSilk
C6, C7: 100nF; C_0603_1608Metric_NoSilk
C8, C9: 47pF; C_0402_1005Metric_NoSilk
C10, C11, C12, C13, C14: 1µF; C_0402_1005Metric_NoSilk
C25: 4.7µF; C_0603_1608Metric_NoSilk
C26: 10µF; C_0402_1005Metric_NoSilk
C27: 10µF; C_1206_3216Metric_NoSilk
D1: Red; LED_0603_1608Metric_SmallSilk
D2, D4, D5, D8, D9: 5.5V; ST_QFN1610_1_NoSilk
D3: Yellow; LED_0603_1608Metric_SmallSilk
D6: Pink; LED_0603_1608Metric_SmallSilk
D10: Green; LED_0603_1608Metric_SmallSilk
D11: Blue; LED_0603_1608Metric_SmallSilk
D12: Iceblue; LED_0603_1608Metric_SmallSilk
L2: 10µH LPS4018-103MRB; L_Coilcraft_LPS4018_NoSilk
Q1: BSD235C; SOT-363_SC-70-6
Q2: PJC7407_R1; SOT-323_SC-70_NoSilk
R1, R19, R25: 1MΩ; R_0402_1005Metric_NoSilk
R2, R4, R26, R27, R30, R31, R32, R35, R36, R38: 2.2kΩ; R_0402_1005Metric_NoSilk
R5, R6, R7, R8, R9: 4.7kΩ; R_0402_1005Metric_NoSilk
R10, R14, R15, R16, R17: 47kΩ; R_0402_1005Metric_NoSilk
R18: 2MΩ; R_0402_1005Metric_NoSilk
R23: 10kΩ; R_0402_1005Metric_NoSilk
R28: 71.5kΩ; R_0402_1005Metric_NoSilk
R29: 910kΩ; R_0402_1005Metric_NoSilk
U7: OLED-1.5-SSD1327; OLED_SSD1327_1.5
U9: TLV61046ADB; SOT-23-6_NoSilk
U10: NavigationSwitch_JS1400; NavigationStick_ESwitch-JS1400AFQ
U12: 74AHCV17A; TSSOP-14_4.4x5mm_P0.65mm_NoSilk
U15, U16: 150060RV75240; 150060RV75240_Smaller
U19: (no value)

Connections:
+3V3: C1.2, C2.2, C5.1, C23.1, C26.2, L2.1, Q2.2 (S), R5.2, R6.2, R7.2, R8.2, R9.2, R23.1, U7.5 (VCI), U7.6 (VDO), U9.4 (EN), U9.6 (VI), U12.14 (VCC), U19.4; also elsewhere on the board
+12V: C3.1, C6.1, C7.1, C8.1, C9.1, C21.1, C27.1, R25.1, U7.2 (VCC), U7.24 (VCC), U9.5 (VOUT)
+Vin: C4.2, Q1.4 (SP), R1.2, R19.2, U19.5 (VDD); also elsewhere on the board
/User Interface/FB: R25.2, R28.1, U9.3 (FB)
/User Interface/Iref: R29.2, U7.10 (Iref)
/User Interface/LED-PWM_+3.3V: D10.2 (A), D11.2 (A), D12.2 (A), Q2.3 (D), R26.1, U15.3 (AR), U15.4 (AG), U16.3 (AR), U16.4 (AG)
/User Interface/LED-PWM_+Vin: Q1.3 (DP), R2.1, R4.1
/User Interface/SW: L2.2, U9.1 (SW)
/User Interface/VCOMH: C25.1, U7.3 (VCOMH)
GNSS-Fence-LED: R30.2; also elsewhere on the board
GNSS-PPS-LED: R32.2; also elsewhere on the board
GNSS-RTK-LED: R31.2; also elsewhere on the board
LED-1-GRN: R38.2; also elsewhere on the board
LED-1-RED: R27.2; also elsewhere on the board
LED-2-GRN: R36.2; also elsewhere on the board
LED-2-RED: R35.2; also elsewhere on the board
LED_PWM/VIN: U19.1; also elsewhere on the board
NAV-A: U12.6 (3Y); also elsewhere on the board
NAV-A-BUF: C12.1, R15.2, U12.9 (4A)
NAV-B: U12.8 (4Y); also elsewhere on the board
NAV-B-BUF: C11.1, R16.2, U12.5 (3A)
NAV-C: U12.2 (1Y); also elsewhere on the board
NAV-C-BUF: C14.1, R10.2, U12.1 (1A)
NAV-D: U12.4 (2Y); also elsewhere on the board
NAV-D-BUF: C10.1, R17.2, U12.3 (2A)
NAV-SW: U12.10 (5Y); also elsewhere on the board
NAV-SW-BUF: C13.1, R14.2, U12.11 (5A)
unnamed: D1.2 (A), R2.2
unnamed: D2.1 (K), R5.1, R15.1, U10.1 (A)
unnamed: D3.2 (A), R4.2
unnamed: D4.1 (K), R8.1, R14.1, U10.2 (BTN)
unnamed: D5.1 (K), R9.1, R10.1, U10.3 (C)
unnamed: D6.2 (A), R26.2
unnamed: D8.1 (K), R6.1, R16.1, U10.4 (B)
unnamed: D9.1 (K), R7.1, R17.1, U10.6 (D)
unnamed: D10.1 (K), R30.1
unnamed: D11.1 (K), R31.1
unnamed: D12.1 (K), R32.1
unnamed: Q1.2 (GN), R1.1, R18.2, U19.2
unnamed: R27.1, U16.2 (KR)
unnamed: R35.1, U15.2 (KR)
unnamed: R36.1, U15.1 (KG)
unnamed: R38.1, U16.1 (KG)
OLED_CS: U7.11 (CS); also elsewhere on the board
OLED_DC: U7.13 (D/C); also elsewhere on the board
OLED_RESET: R23.2, U7.12 (RES); also elsewhere on the board
VSPI_CLK: U7.16 (D0); also elsewhere on the board
VSPI_MOSI: U7.17 (D1); also elsewhere on the board
~CHG: D3.1 (K); also elsewhere on the board
~EN-LED: Q1.5 (GP), Q1.6 (DN), Q2.1 (G), R19.1
~PGOOD: D1.1 (K); also elsewhere on the board

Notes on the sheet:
Hardware debouncing with Schmitt-Trigger because ESP's interrupts are cursed. https://github.com/espressif/arduino-esp32/issues/4172
Nav Switch
PCB #1
ESP / System LEDs
PPS
1.5” OLED Screen
RTK
System Power
Diodes: ST ESDA7P120-1U1M
50mA
Replaced w/ AOSN21319 due to availability.
12V Step Up (for OLED)
Battery LEDs
Power Good
Charge
GNSS Status LEDs
Capacitors: 10µF: GRJ155R60J106ME11D
LEDs
Geofence
LED-1
LED-2

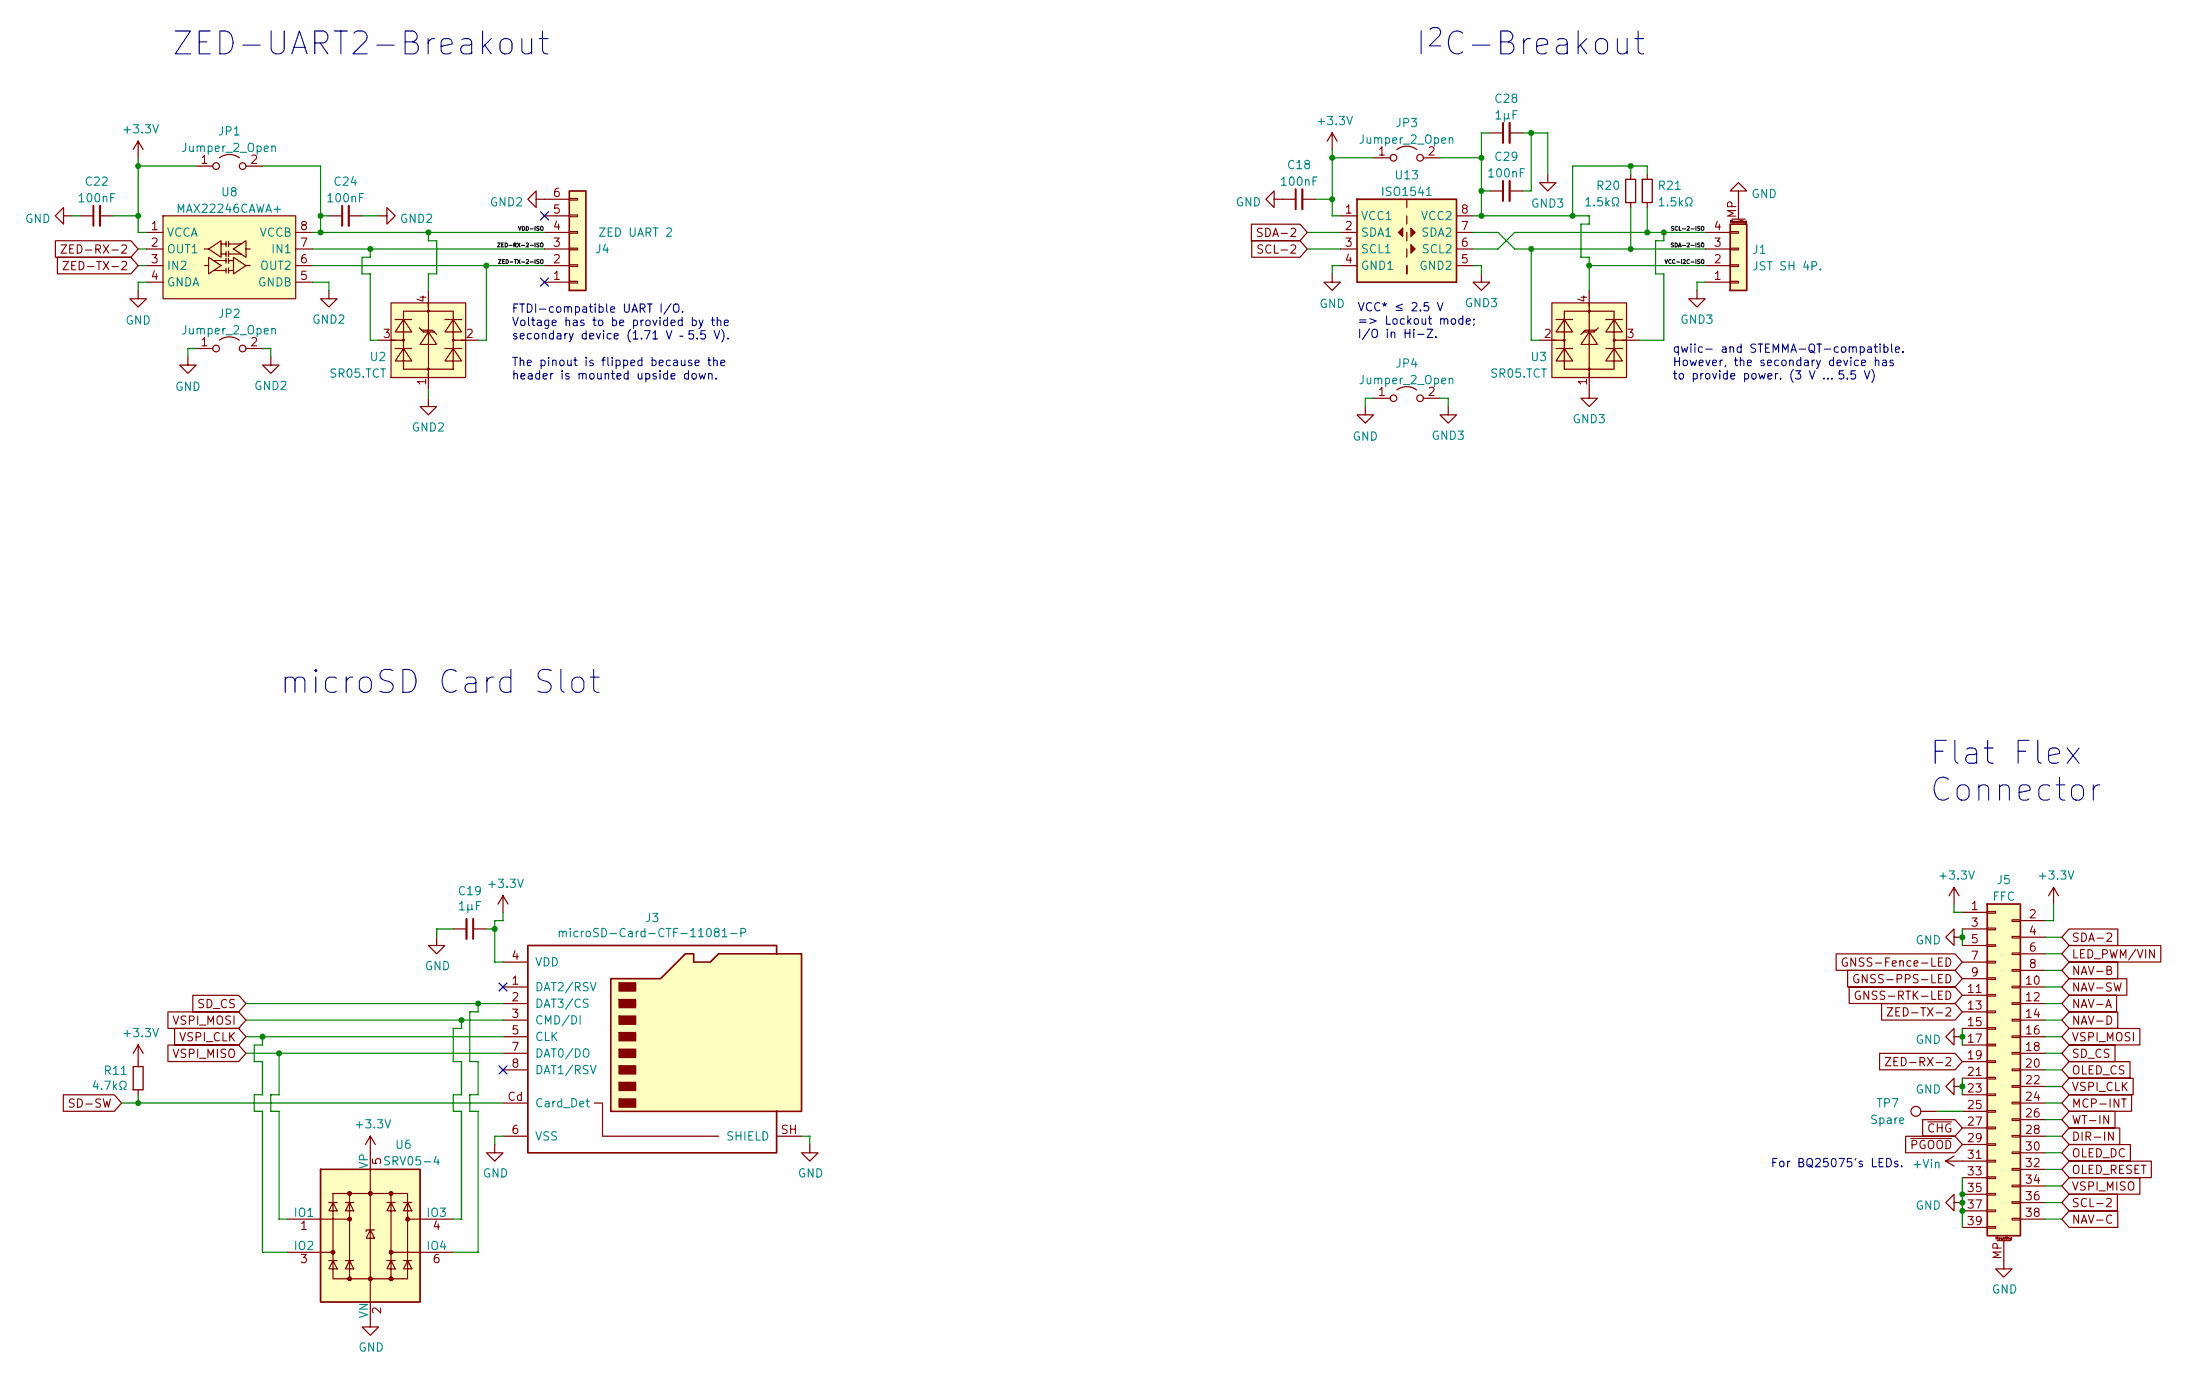
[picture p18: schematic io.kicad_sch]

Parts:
C18, C22, C24, C29: 100nF; C_0402_1005Metric_NoSilk
C19, C28: 1µF; C_0402_1005Metric_NoSilk
J1: JST SH 4P.; JST_SH_SM04B-SRSS-TB_1x04-1MP_P1.00mm_Horizontal
J3: microSD-Card-CTF-11081-P
J4: ZED UART 2; PinSocket_2.54mm_01x06_Horizontal_SMD
J5: FFC; 5025983993
JP1, JP2, JP3, JP4: Jumper_2_Open; R_0805_2012Metric_NoSilk_DNP
R11: 4.7kΩ; R_0402_1005Metric_NoSilk
R20, R21: 1.5kΩ; R_0402_1005Metric_NoSilk
TP7: Spare; TestPoint_Pad_D1.0mm_NoSIlk
U2, U3: SR05.TCT; SOT143-4L-slim
U6: SRV05-4; SOT-23-6_NoSilk
U8: MAX22246CAWA+; SOIC-8W_3.9x_P1.27mm_NoSilk
U13: ISO1541; SOIC-8_3.9x4.9mm_P1.27mm_NoSilk

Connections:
+3V3: C18.2, C19.1, C22.2, J3.4 (VDD), J5.1, J5.2, JP1.1 (A), JP3.1 (A), R11.2, U6.5 (VP), U8.1 (VCCA), U13.1 (VCC1); also elsewhere on the board
+Vin: J5.31; also elsewhere on the board
/Connectors/SCL-2-ISO: J1.4, R21.2, U3.3 (CH2), U13.6 (SCL2)
/Connectors/SDA-2-ISO: J1.3, R20.1, U3.2 (CH1), U13.7 (SDA2)
/Connectors/VCC-I2C-ISO: C28.1, C29.1, J1.2, JP3.2 (B), R20.2, R21.1, U3.4 (VBUS), U13.8 (VCC2)
/Connectors/VDD-ISO: C24.1, J4.4, JP1.2 (B), U2.4 (VBUS), U8.8 (VCCB)
/Connectors/ZED-RX-2-ISO: J4.3, U2.3 (CH2), U8.7 (IN1)
/Connectors/ZED-TX-2-ISO: J4.2, U2.2 (CH1), U8.6 (OUT2)
DIR-IN: J5.28; also elsewhere on the board
GND2: C24.2, J4.6, JP2.2 (B), U2.1 (GND), U8.5 (GNDB)
GND3: C28.2, C29.2, J1.1, JP4.2 (B), U3.1 (GND), U13.5 (GND2)
GNSS-Fence-LED: J5.7; also elsewhere on the board
GNSS-PPS-LED: J5.9; also elsewhere on the board
GNSS-RTK-LED: J5.11; also elsewhere on the board
LED_PWM/VIN: J5.6; also elsewhere on the board
MCP-INT: J5.24; also elsewhere on the board
NAV-A: J5.12; also elsewhere on the board
NAV-B: J5.8; also elsewhere on the board
NAV-C: J5.38; also elsewhere on the board
NAV-D: J5.14; also elsewhere on the board
NAV-SW: J5.10; also elsewhere on the board
unnamed: J5.25, TP7.1
OLED_CS: J5.20; also elsewhere on the board
OLED_DC: J5.30; also elsewhere on the board
OLED_RESET: J5.32; also elsewhere on the board
SCL-2: J5.36, U13.3 (SCL1); also elsewhere on the board
SD-SW: J3.Cd (Card_Det), R11.1; also elsewhere on the board
SDA-2: J5.4, U13.2 (SDA1); also elsewhere on the board
SD_CS: J3.2 (DAT3/CS), J5.18, U6.6 (IO4)
VSPI_CLK: J3.5 (CLK), J5.22, U6.3 (IO2); also elsewhere on the board
VSPI_MISO: J3.7 (DAT0/DO), J5.34, U6.1 (IO1)
VSPI_MOSI: J3.3 (CMD/DI), J5.16, U6.4 (IO3); also elsewhere on the board
WT-IN: J5.26; also elsewhere on the board
ZED-RX-2: J5.19, U8.2 (OUT1)
ZED-TX-2: J5.13, U8.3 (IN2)
~CHG: J5.27; also elsewhere on the board
~PGOOD: J5.29; also elsewhere on the board

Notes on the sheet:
I^{2}C-Breakout
VCC* ≤ 2.5 V => Lockout mode; I/O in Hi-Z.
qwiic- and STEMMA-QT-compatible. However, the secondary device has to provide power. (3 V … 5.5 V)
Flat Flex Connector
For BQ25075's LEDs.
microSD Card Slot
FTDI-compatible UART I/O. Voltage has to be provided by the secondary device (1.71 V – 5.5 V). The pinout is flipped because the header is mounted upside down.
ZED-UART2-Breakout

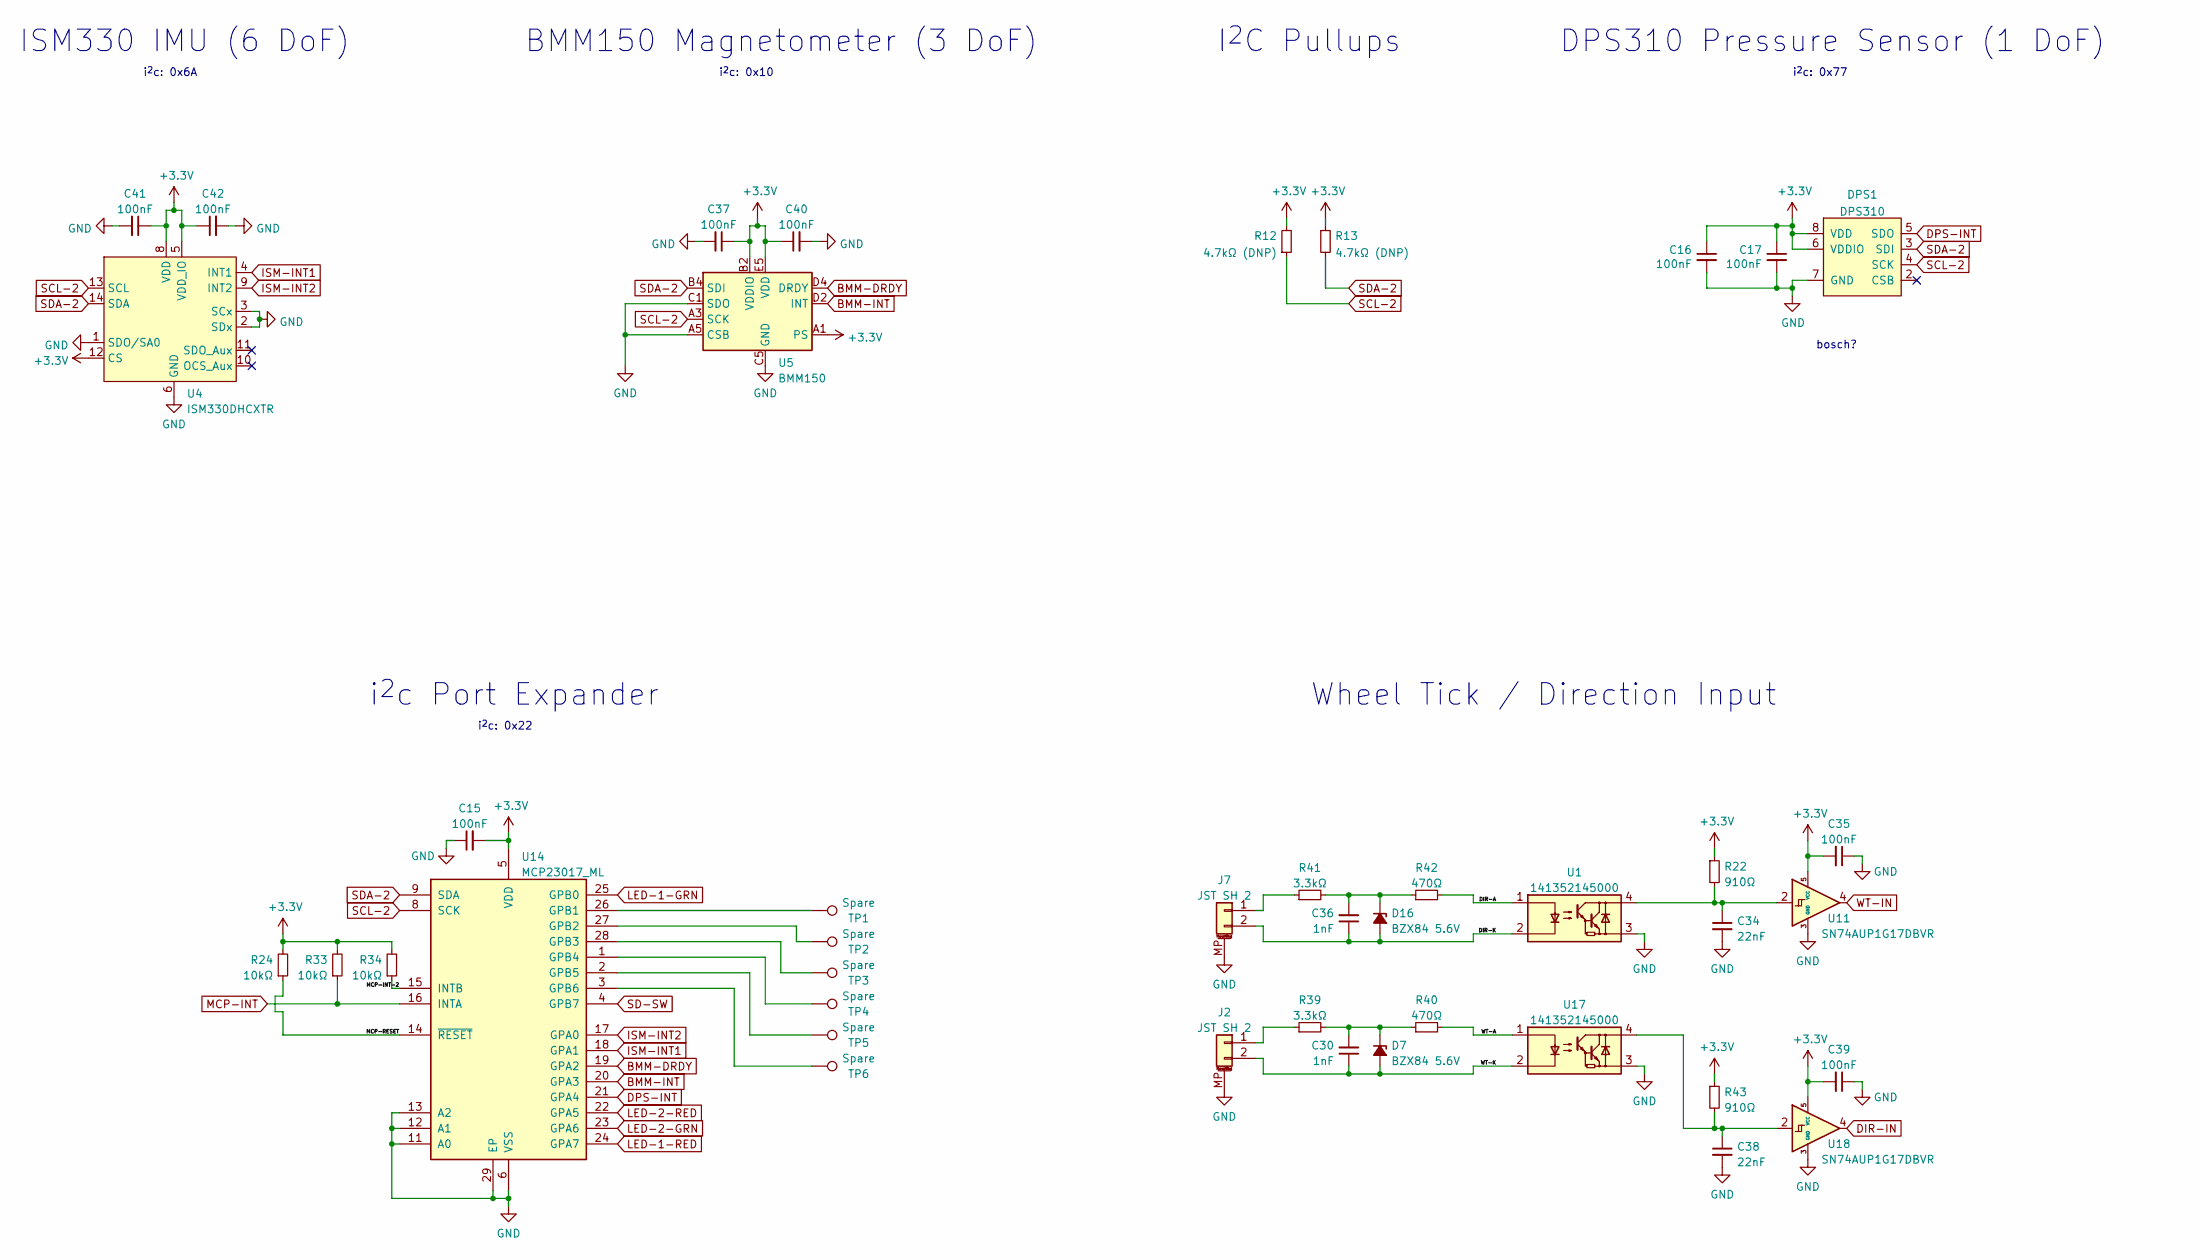
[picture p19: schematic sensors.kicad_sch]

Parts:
C15, C16, C17, C35, C37, C39, C40, C41, C42: 100nF; C_0402_1005Metric_NoSilk
C30, C36: 1nF; C_0402_1005Metric_NoSilk
C34, C38: 22nF; C_0402_1005Metric_NoSilk
D7, D16: BZX84 5.6V; SOT-23_NoSilk
DPS1: DPS310
J2, J7: JST SH 2; JST_SH_SM02B-SRSS-TB_1x02-1MP_P1.00mm_Horizontal_NoSilk
R12, R13: 4.7kΩ (DNP); R_0402_1005Metric_NoSilk
R22, R43: 910Ω; R_0402_1005Metric_NoSilk
R24, R33, R34: 10kΩ; R_0402_1005Metric_NoSilk
R39, R41: 3.3kΩ; R_0603_1608Metric_NoSilk
R40, R42: 470Ω; R_0402_1005Metric_NoSilk
TP1, TP2, TP3, TP4, TP5, TP6: Spare; TestPoint_Pad_D1.0mm_NoSIlk
U1, U17: 141352145000
U4: ISM330DHCXTR; LGA-14L_1.5x3.0x0.86_ST
U5: BMM150; WLCSP-12_1.56x1.56mm_P0.4mm_NoSilk
U11, U18: SN74AUP1G17DBVR; SOT-23-5_NoSilk
U14: MCP23017_ML; QFN-28-1EP_6x6mm_P0.65mm_EP4.25x4.25mm_NoSilk

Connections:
+3V3: C15.2, C16.1, C17.1, C35.2, C37.1, C39.2, C40.1, C41.1, C42.1, DPS1.6 (VDDIO), DPS1.8 (VDD), R12.2, R13.1, R22.1, R24.2, R33.2, R34.2, R43.1, U4.5 (VDD_IO), U4.8 (VDD), U4.12 (CS), U5.A1 (PS), U5.B2 (VDDIO), U5.E5 (VDD), U11.5 (VCC), U14.5 (VDD), U18.5 (VCC); also elsewhere on the board
/Sensors/DIR-A: R42.2, U1.1
/Sensors/DIR-K: C36.1, D16.1 (A), J7.2, U1.2
/Sensors/MCP-INT-2: R34.1, U14.15 (INTB)
/Sensors/MCP-RESET: R24.1, U14.14 (~RESET)
/Sensors/WT-A: R40.2, U17.1
/Sensors/WT-K: C30.1, D7.1 (A), J2.2, U17.2
BMM-DRDY: U5.D4 (DRDY), U14.19 (GPA2)
BMM-INT: U5.D2 (INT), U14.20 (GPA3)
DIR-IN: U18.4; also elsewhere on the board
DPS-INT: DPS1.5 (SDO), U14.21 (GPA4)
ISM-INT1: U4.4 (INT1), U14.18 (GPA1)
ISM-INT2: U4.9 (INT2), U14.17 (GPA0)
LED-1-GRN: U14.25 (GPB0); also elsewhere on the board
LED-1-RED: U14.24 (GPA7); also elsewhere on the board
LED-2-GRN: U14.23 (GPA6); also elsewhere on the board
LED-2-RED: U14.22 (GPA5); also elsewhere on the board
MCP-INT: R33.1, U14.16 (INTA); also elsewhere on the board
unnamed: C30.2, D7.3 (K), R39.2, R40.1
unnamed: C34.1, R22.2, U1.4, U11.2
unnamed: C36.2, D16.3 (K), R41.2, R42.1
unnamed: C38.1, R43.2, U17.4, U18.2
unnamed: J2.1, R39.1
unnamed: J7.1, R41.1
unnamed: TP1.1, U14.26 (GPB1)
unnamed: TP2.1, U14.27 (GPB2)
unnamed: TP3.1, U14.28 (GPB3)
unnamed: TP4.1, U14.1 (GPB4)
unnamed: TP5.1, U14.2 (GPB5)
unnamed: TP6.1, U14.3 (GPB6)
SCL-2: DPS1.4 (SCK), R12.1, U4.13 (SCL), U5.A3 (SCK), U14.8 (SCK); also elsewhere on the board
SD-SW: U14.4 (GPB7); also elsewhere on the board
SDA-2: DPS1.3 (SDI), R13.2, U4.14 (SDA), U5.B4 (SDI), U14.9 (SDA); also elsewhere on the board
WT-IN: U11.4; also elsewhere on the board

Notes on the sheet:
ISM330 IMU (6 DoF)
i^{2}c: 0x10
i^{2}c: 0x77
i^{2}c: 0x6A
i^{2}c Port Expander
DPS310 Pressure Sensor (1 DoF)
I^{2}C Pullups
i^{2}c: 0x22
Wheel Tick / Direction Input
BMM150 Magnetometer (3 DoF)
bosch?

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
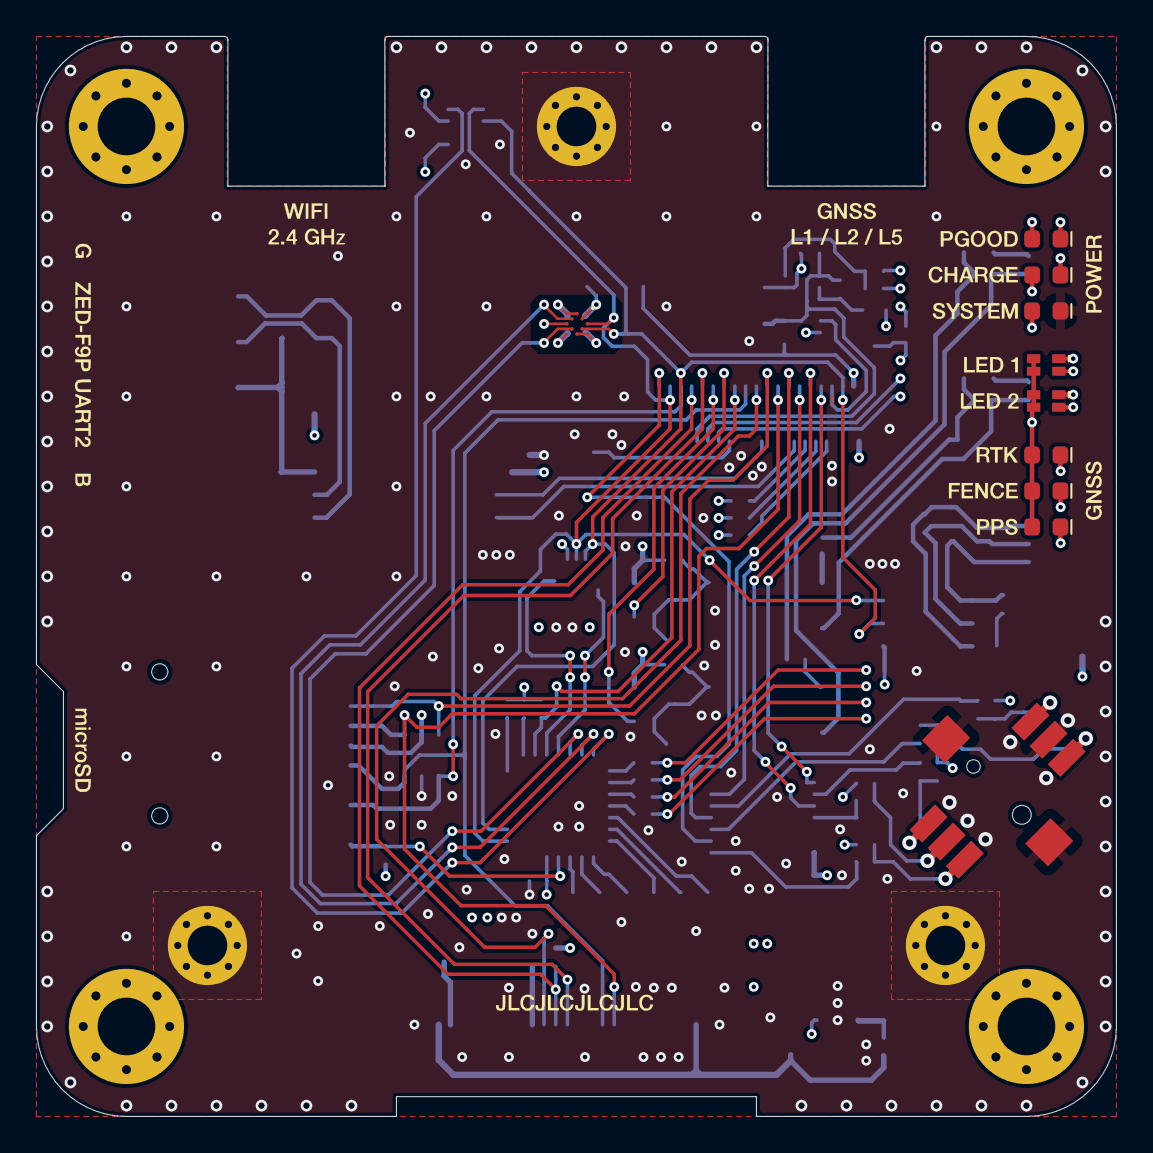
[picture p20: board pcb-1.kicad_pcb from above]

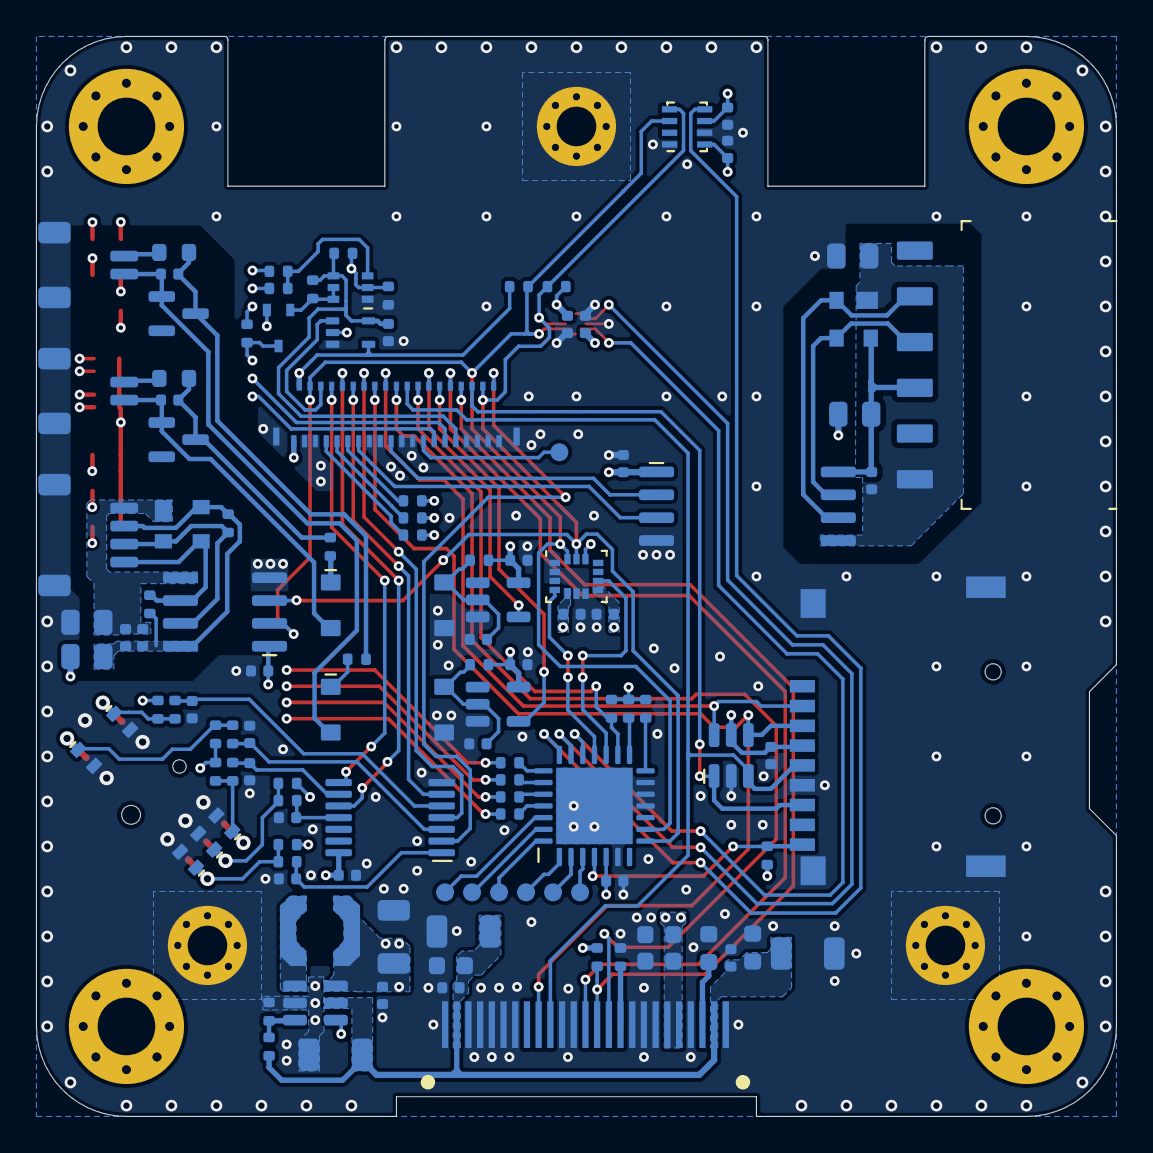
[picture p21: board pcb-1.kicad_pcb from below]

Board: 4 copper layers, 60.0 x 60.0 mm, 139 parts (121 on the bottom side), 94 nets.

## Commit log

2022-05-26 finalised Hardware Rev. B
    [PCB-3.kicad_pcb, PCB-3.kicad_sch, esp.kicad_sch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]
2022-10-11 added photos to docu
    [esp.kicad_sch, io.kicad_sch, pcb-1.kicad_sch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]
